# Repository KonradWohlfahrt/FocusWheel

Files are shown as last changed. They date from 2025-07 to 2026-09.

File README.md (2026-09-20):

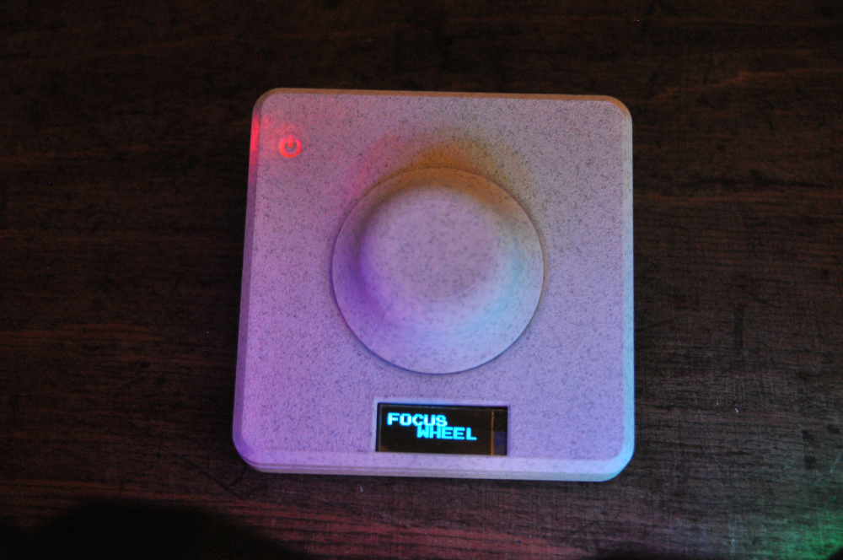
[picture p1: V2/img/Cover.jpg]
Cover


# Focus Wheel 2.0  
**Overview**  
Focus Wheel 2.0 is a compact, standalone focus and time-management device designed to help you stay productive during study sessions or focused work. It combines a clean, minimal design with touch controls, visual feedback, and flexible timer logic, all powered by a rechargeable battery. This second iteration is a major step up from the original Focus Wheel. It introduces battery operation with power-path management, touch-based controls, an integrated LED ring, and a more refined enclosure. The result is a polished desk companion that’s easy to use, highly customizable, and fun to build:  

[Instructables Guide](https://www.instructables.com/Focus-Wheel-20-Your-Next-Gen-Study-Assistant/)  

**Key Features**  
- *Four independent timers*  
Each timer can be configured individually with its own work and break durations. All settings are stored in EEPROM and persist across power cycles.
- *Built-in 20-20 rule*  
Optional eye-break reminders during work sessions help reduce eye strain. The reminder timing can be adjusted in software.
- *Touch-based controls*  
Capacitive touch buttons replace traditional mechanical switches, keeping the design clean and minimal.
- *Rotary encoder interface*  
A rotary encoder is used for intuitive navigation, timer selection, and value adjustments.
- *Integrated LED ring*  
WS2812B LEDs are placed directly on the PCB and provide visual feedback for timers, states, and effects.
- *OLED display*  
A small I2C OLED shows timer status, menus, battery information, and system feedback.
- *Sound and melodies*  
A passive buzzer allows the device to play different tones and melodies for notifications and timer events.
- *Battery powered with USB-C charging*  
The device runs on a LiPo battery and supports simultaneous charging and operation thanks to power-path management.
- *Battery monitoring & protection*  
Battery voltage, charge state, and power source (USB or battery) are monitored in software, with low-voltage shutdown for safety.  

***
# Materials:
| Component | Amount | Silkscreen label |
|:---|:---:|---:|
| 100n 0603 | 22 | C1,C4,C8,C12,C17,C19,C21-C36 |
| 100p 0805 | 1 | C15 |
| 100r 0805 | 2 | R9,R12 |
| 100u 1206 | 1 | C20 |
| 10k 0805 | 8 | R6,R11,R13,R18-R21,R28 |
| 10u 0805 | 5 | C3,C9,C11,C14,C16 |
| 15k 0805 | 1 | R15 |
| 1k 0805 | 4 | R7,R8,R10,R27 |
| 1k5 0805 | 1 | R4 |
| 1N4001 SMA | 1 | D3 |
| 1u 0805 | 3 | C2,C5,C18 |
| 2.2uH APH0420 | 1 | L1 |
| 309k 0805 | 1 | R17 |
| 330r 0805 | 1 | R24 |
| 33k 0805 | 1 | R25 |
| 39k 0805 | 1 | R3 |
| 3k9 0805 | 1 | R5 |
| 4.7u 0805 | 4 | C6,C7,C10,C13 |
| 4.7uH ANR3015 | 1 | L2 |
| 47k 0805 | 1 | R26 |
| 4k7 0805 | 2 | R22,R23 |
| 5k1 0805 | 2 | R1,R2 |
| 68k 0805 | 1 | R14 |
| 976k 0805 | 1 | R16 |
| AO3400A SOT-23 | 1 | Q3 |
| BQ24075RGT | 1 | U2 |
| Buzzer MLT-7525 | 1 | BZ1 |
| JST PH2.00mm 2P Horizontal | 1 | J2 |
| DW01A SOT-23-6 | 1 | U3 |
| ESP32-C3-WROOM-02 | 1 | U7 |
| FS8205A SOT-23-6 | 1 | Q1 |
| IRLML6402 SOT-23 | 1 | Q2 |
| LED 3.0mm | 2 | D1,D2 |
| MCP1640Cx-xCHY SOT-23-6 | 1 | U6 |
| MMBT2222A SOT-23 | 1 | Q4 |
| OLED I2C 0.91" | 1 | U10 |
| Rotary Encoder | 1 | SW1 |
| SN74LV1T34DBV SOT-23-5 | 1 | U11 |
| SS34 SMA | 1 | D20 |
| TLV62569DBV SOT-23-5 | 1 | U5 |
| TTP223 Touch Module | 3 | U4,U8,U9 |
| USB-C 16P | 1 | J1 |
| USBLC6-2SC6 SOT-23-6 | 1 | U1 |
| WS2812B 5050 | 16 | D4-D19 |
| Custom PCB | 1 | - |
| 3D printed housing | 1 | - |
| 303450 500mAh LiPo battery | 1 | - |
| M3 3x4.5mm threaded heat inserts | 6 | - |
| M3x4mm screw | 2 | - |
| M3x10mm screw | 4 | - |

***
# Schematic & PCB:
_Schematic of the Focus Wheel V2.1_
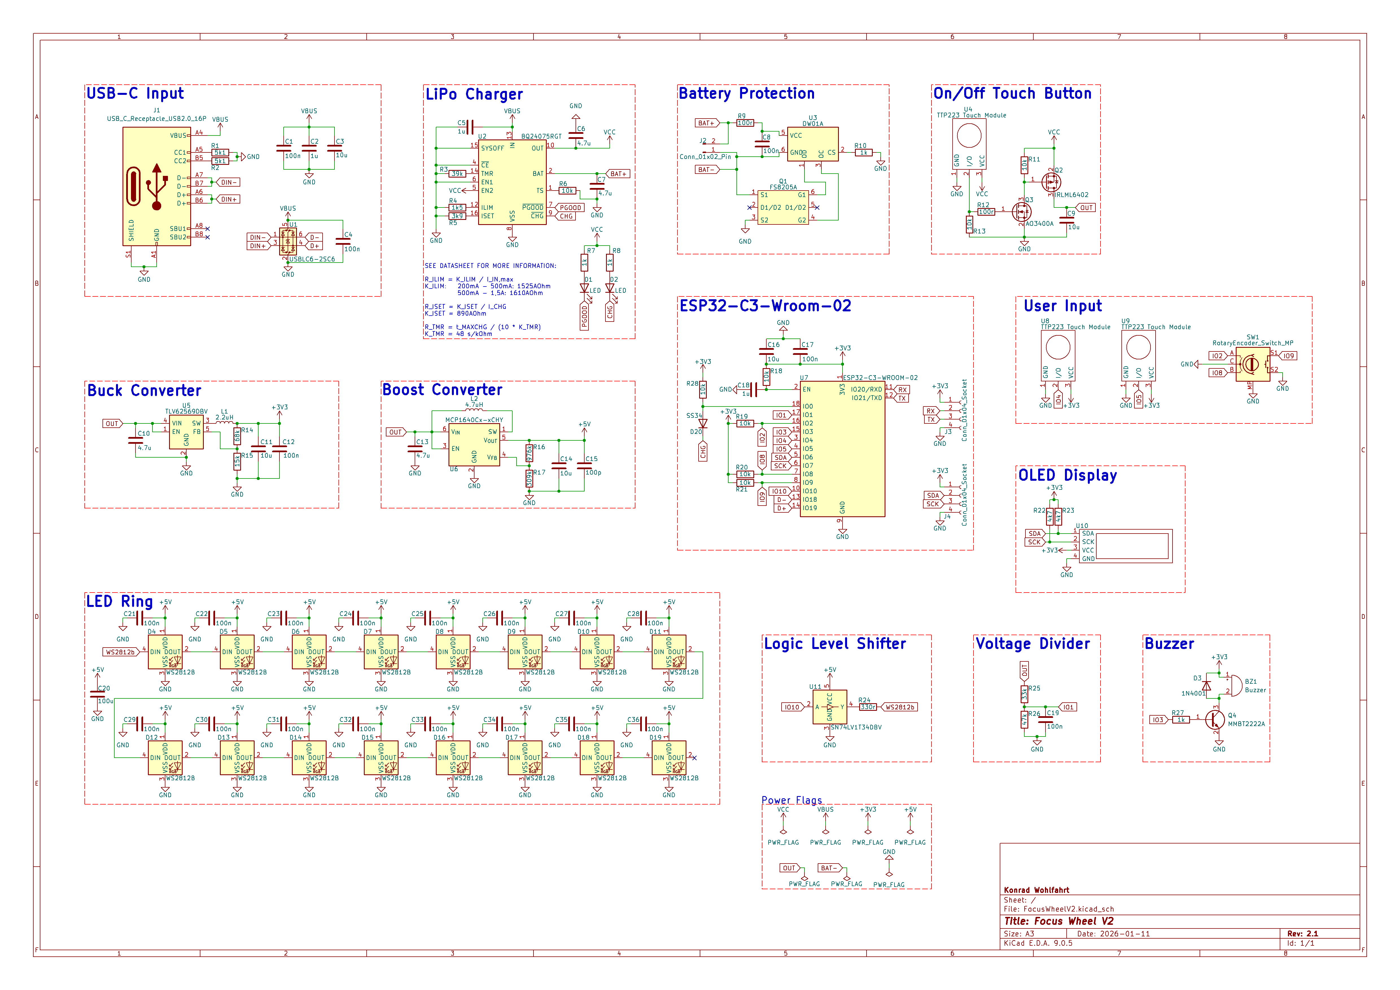
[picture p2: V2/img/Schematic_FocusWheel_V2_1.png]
Schematic

_Lables for soldering components_
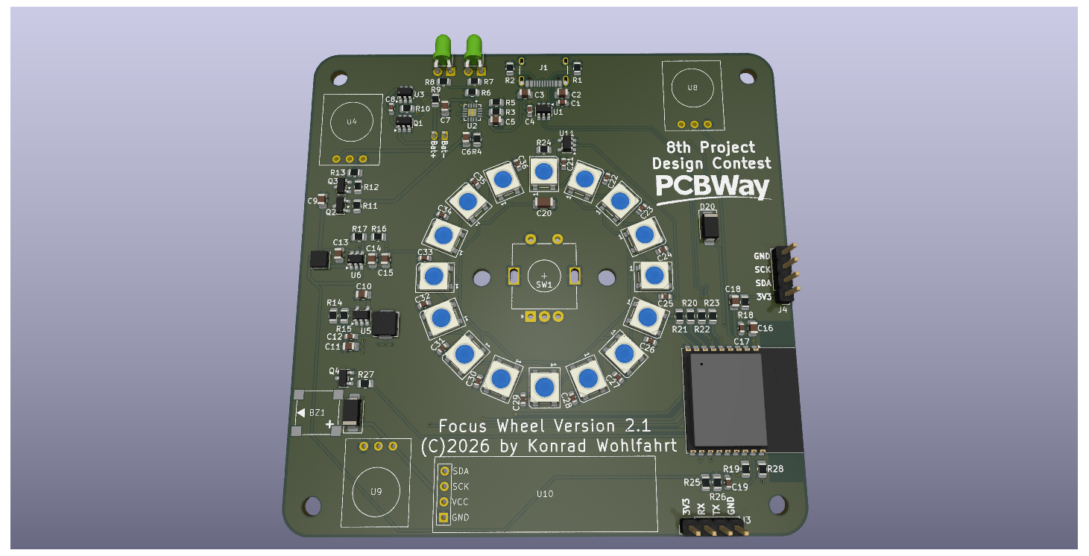
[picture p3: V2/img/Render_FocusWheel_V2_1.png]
PCB Render


***
# Programming
Programmed with the Arduino IDE and ESP32 board manager. Install the following libraries:
- [DonutStudioTimer](https://github.com/KonradWohlfahrt/Arduino-Timer-Library)
- [RotaryEncoder](https://github.com/mathertel/RotaryEncoder)
- [FastLED](https://github.com/FastLED/FastLED)
- [U8g2](https://github.com/olikraus/u8g2)

**Uploading:**  
Board: `ESP32C3 Dev Module`\
Settings:
```cpp
USB CDC On Boot: "Enabled" <- to make USB Serial work  
CPU Frequency: "160MHz (WiFi)"  
Core Debug Level: "None"  
Erase All Flash Before Sketch Upload: "Disabled"  
Flash Frequency: "80MHz"  
Flash Mode: "QIO"  
Flash Size: "4MB (32Mb)"  
JTAG Adapter: "Disabled"  
Partition Scheme: "Default 4MB with spiffs (1.2MB APP/1.5MB SPIFFS)"  
Upload Speed: "921600"  
Zigbee Mode: "Disabled"  
Programmer: "Esptool"  
```
Connection via USB-C.\
Press the knob button (Flash) when powering up the device for the first time.

***
# 3D Printing
Print `FocusWheel_Bottom` and `FocusWheel_Top` - depending on what components you would like to use. Finally, print `Knob`. Put in the six threaded heat inserts and screw everything together. The knob slides on top.
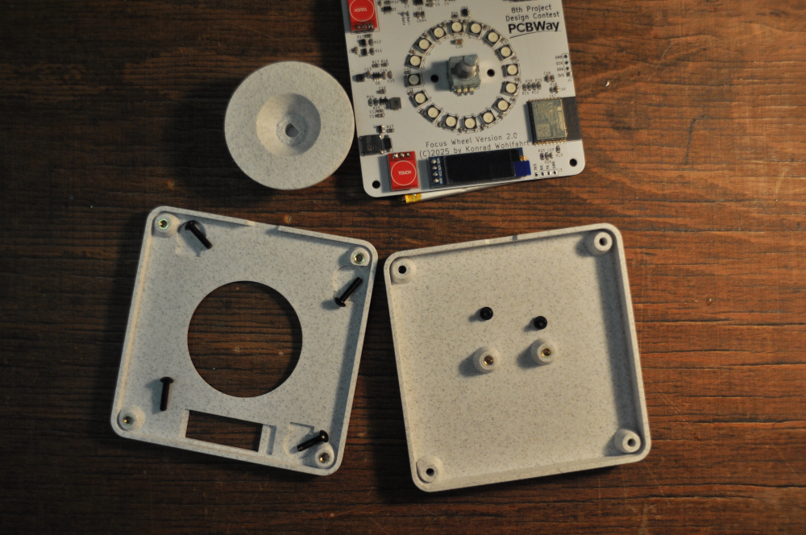
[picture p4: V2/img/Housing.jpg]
Housing


***
# Functions
The following button functions are used:
- bottom button: enable/disable sound
- middle button: start timer, pause timer, change selection (rotation)
- top button: skip timers, enter/exit settings

**Customization & Hacking**  
All firmware is written for the Arduino ecosystem, and the code is intended to be easy to extend and experiment with. This project is fully open to customization. You can:
- Modify timer logic and behaviors
- Change LED effects and animations
- Add or replace melodies
- Adjust UI flow and menu structure

**Final Notes**  
Focus Wheel 2.0 is meant to be both a useful productivity tool and an enjoyable electronics project. Whether you build it as-is or use it as a base for your own ideas, feel free to experiment, improve, and make it your own. If you build one, I’d love to see it—share your version and ideas!  

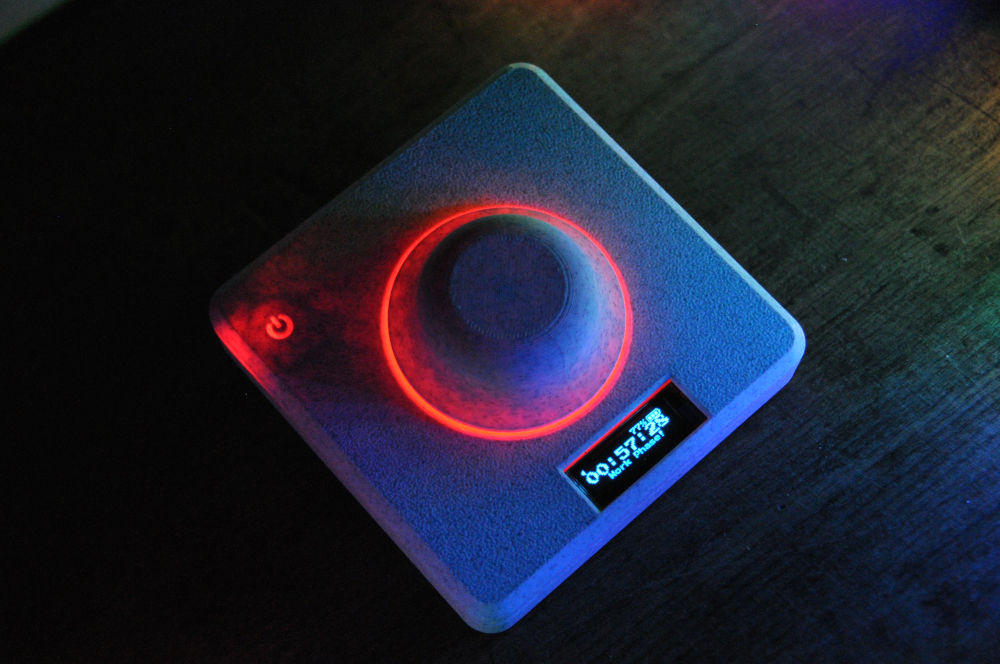
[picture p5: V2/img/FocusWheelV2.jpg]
Focus Wheel V2


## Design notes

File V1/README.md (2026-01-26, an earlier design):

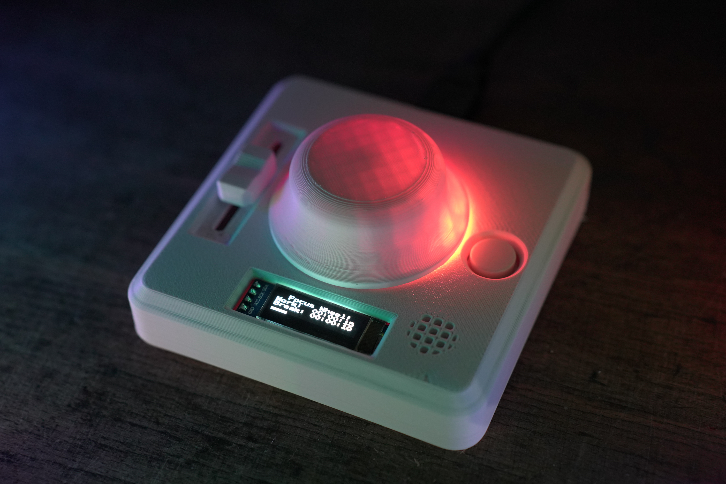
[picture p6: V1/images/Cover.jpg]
Cover


# Focus Wheel
The Focus Wheel is a customizable desk companion designed to help you stay focused, manage study sessions, and take effective breaks. Powered by an ESP32-C3, it features a rotary encoder, buzzer, LED ring, OLED display, and optional slider — all neatly packed into a 3D-printed enclosure.
This project combines hardware and software to provide:
- Multiple focus and break timers
- Visual and audible notifications
- Customizable controls via knob, button, and slider
- Expandability for future features (e.g., media control or BLE functionality)\

Whether you're a student, maker, or just looking to build a functional productivity gadget, the Focus Wheel is a great weekend project — with lots of room for upgrades! Check out the in-depth [guide](https://www.instructables.com/Focus-Wheel-Your-Desk-Study-Buddy/) at instructables!\

**Sponsored by PCBWay!**
This project was made possible with the help of [PCBWay](https://www.pcbway.com/) — a reliable PCB manufacturing service offering high-quality boards at great prices. If you’re looking to bring your electronics project to life with professionally fabricated PCBs, check them out!
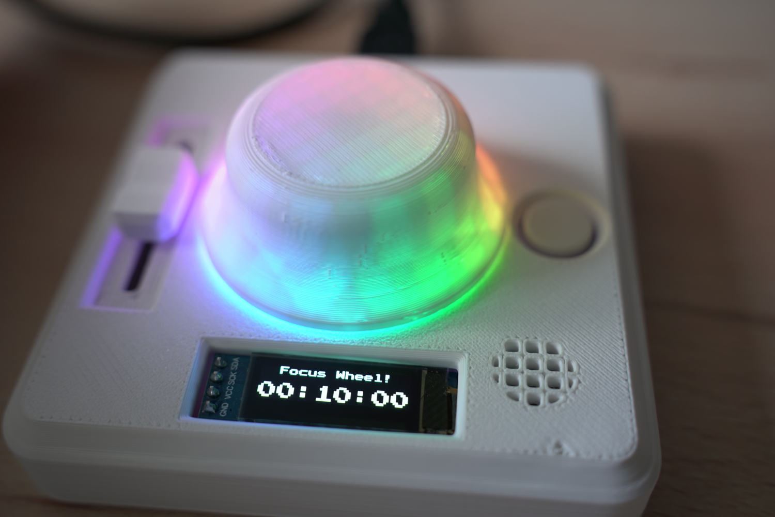
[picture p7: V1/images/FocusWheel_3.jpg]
Focus Wheel


***
# Materials:
| Component | Amount | Silkscreen label |
|:---|:---:|---:|
| custom pcb | 1 | - |
| MMBT2222A | 1 | Q1 |
| 10uF 0805 | 3 | C1,C3,C9 |
| 100nF 0805 | 4 | C2,C4,C8,C11 |
| 1uF 0805 | 2 | C5,C10 |
| 47pF 0805 | 2 | C6,C7 |
| 100uF 1206 | 1 | C12 |
| 10k 0805 | 5 | R1,R2,R5,R6,R11 |
| 0r 0805 | 3 | R3,R4,R7 |
| 330r 0805 | 1 | R8 |
| 33r 0805 | 1 | R9 |
| 1k 0805 | 1 | R10 |
| 220k 0805 | 1 | R12 |
| 100k 0805 | 1 | R13 |
| 45mm fader | 1 | RS1 |
| Rotary encoder | 1 | SW1 |
| Tactile switch 12x12mm | 1 | SW2 |
| SMD switch 3x6x5mm | 1 | KEY1 |
| Buzzer 12x9mm | 1 | BUZZER1 |
| USB3.0 A socket | 1 | USB1 |
| ESP32-C3-WROOM-02 | 1 | U1 |
| AMS1117-3.3V | 1 | U2 |
| 0.91" OLED | 1 | U3 |
| threaded heat insert m3 x 4.5mm | 6 | - |
| M3x14mm screw | 4 | - |
| M3x4mm screw | 2 | - |
| USB-A cable (male to male) | 1 | - |

***
# Schematic:
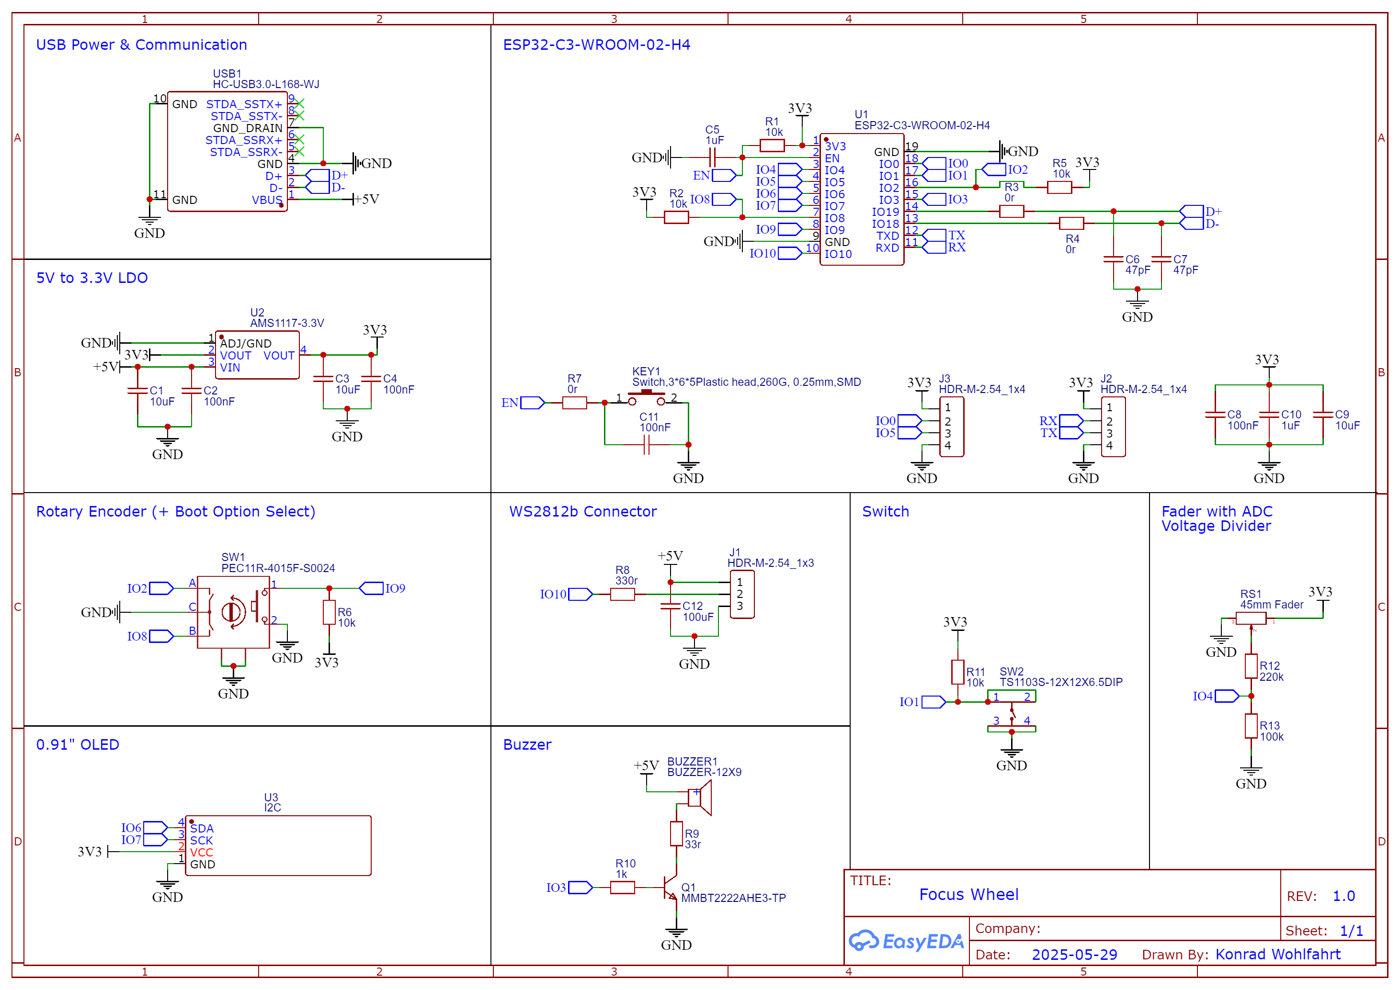
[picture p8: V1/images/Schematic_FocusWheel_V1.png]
Schematic

_Schematic of the Focus Wheel_
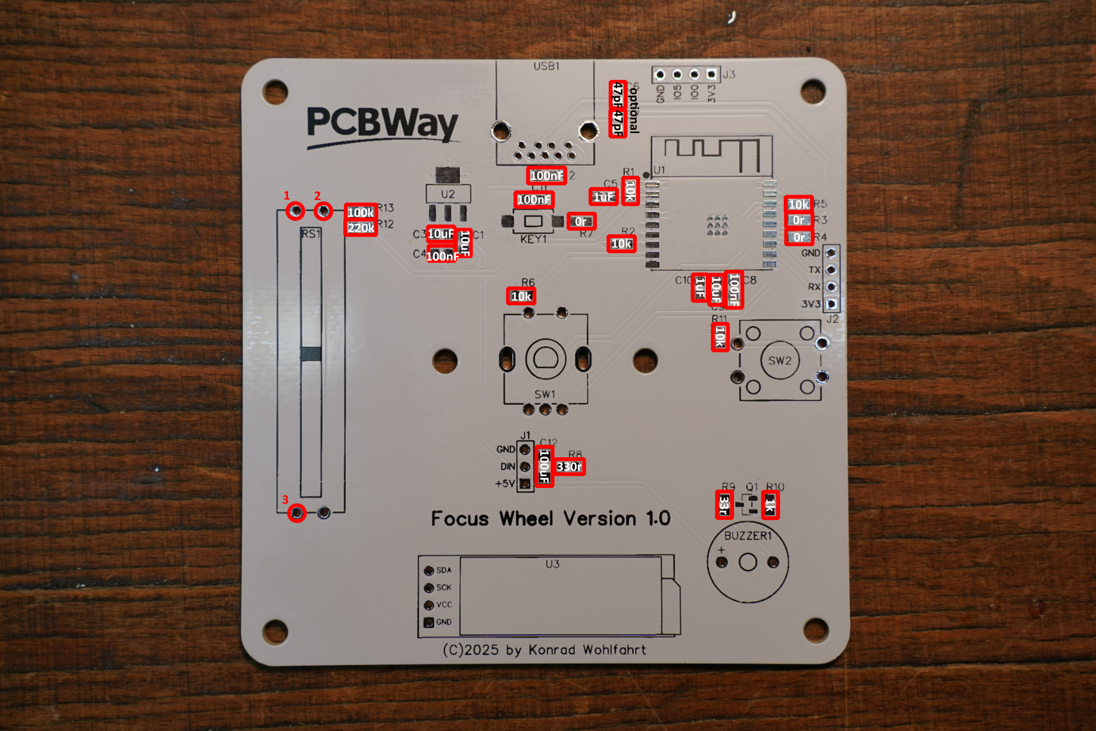
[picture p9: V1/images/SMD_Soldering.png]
Soldering Lables

_Lables for soldering components_

***
# Programming
Programmed with the Arduino IDE and ESP32 board manager. 
Install the following libraries:
- [DonutStudioTimer](https://github.com/KonradWohlfahrt/Arduino-Timer-Library)
- [RotaryEncoder](https://github.com/mathertel/RotaryEncoder)
- [FastLED](https://github.com/FastLED/FastLED)
- [U8g2](https://github.com/olikraus/u8g2)

**Uploading:**
Board: `ESP32C3 Dev Module`\
Settings: default\
Connection via USB cable.\
Press the knob button (Flash) when powering up the device, it also seems uploading works without doing so.

***
# 3D Printing
Print `Housing Bottom` and one of the `Housing Top` options - depending on what components you would like to use. Finally, print both `Fading Knob` and `Knob`. Put in the six threaded heat inserts and screw everything together. The knobs slide on top.
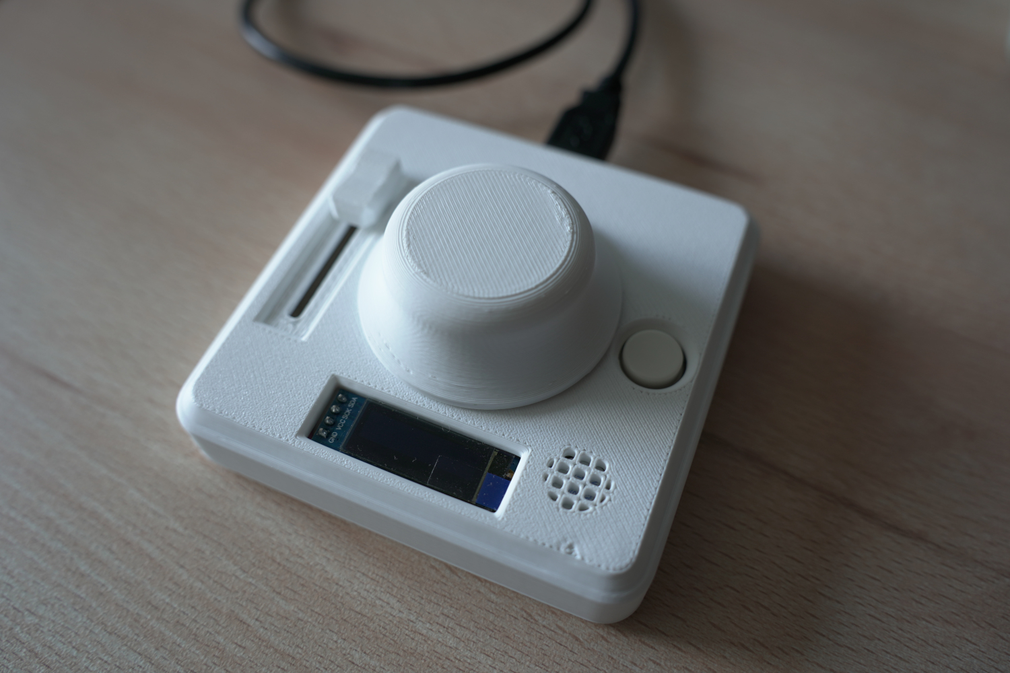
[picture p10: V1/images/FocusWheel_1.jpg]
Focus Wheel


***
# Functions
The following button functions are used in the examples:
- middle button: start timer, pause timer, change selection
- rotating middle button: change timer values or timers
- right button: edit timers, skip timers
- long press right button (only `Timer.ino`): save timer to eeprom

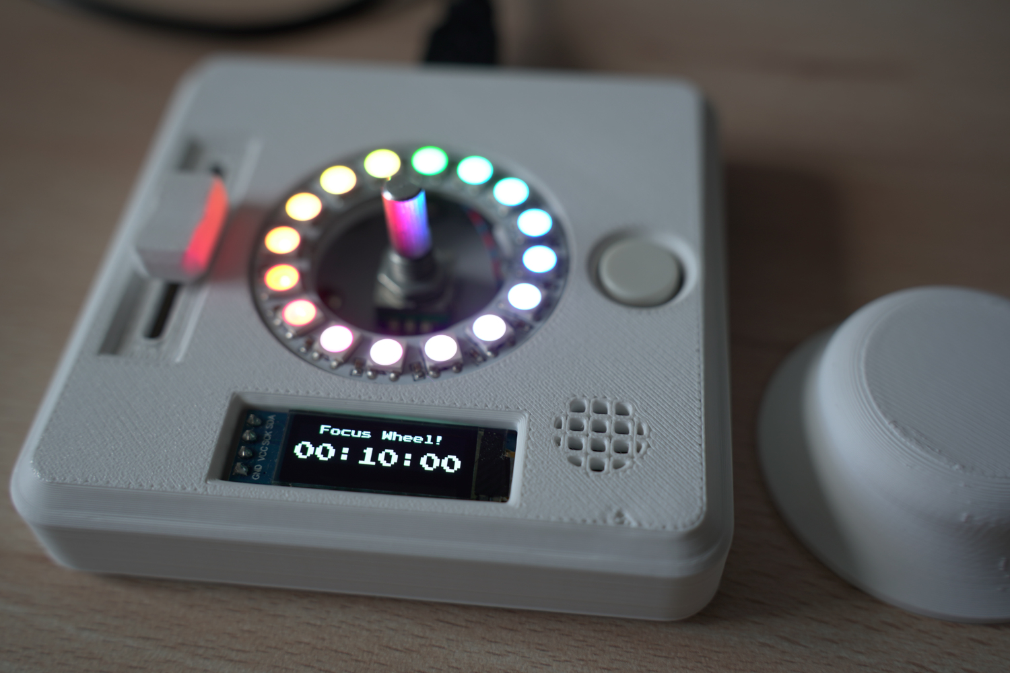
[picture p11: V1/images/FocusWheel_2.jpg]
Focus Wheel


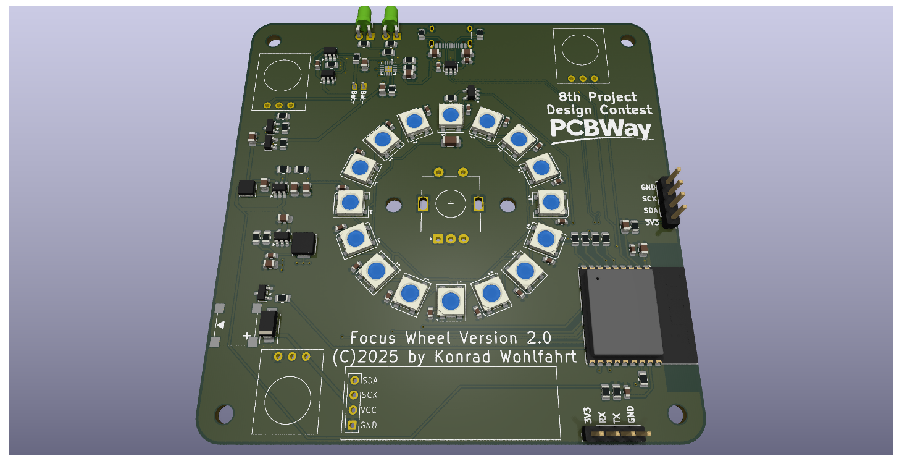
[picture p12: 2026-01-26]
V2/img/Render_FocusWheel_V2.png

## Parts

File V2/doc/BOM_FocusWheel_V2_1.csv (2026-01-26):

Reference | Qty | Value | DNP | Exclude from BOM | Exclude from Board | Footprint | Datasheet
BZ1 | 1 | Buzzer |  |  |  | KonradsLibrary:Huaneng MLT-7525 | ~
C1,C4,C8,C12,C17,C19,C21,C22,C23,C24,C25,C26,C27,C28,C29,C30,C31,C32,C33,C34,C35,C36 | 22 | 100n |  |  |  | Capacitor_SMD:C_0603_1608Metric | ~
C2,C5,C18 | 3 | 1u |  |  |  | Capacitor_SMD:C_0805_2012Metric | ~
C3,C9,C11,C14,C16 | 5 | 10u |  |  |  | Capacitor_SMD:C_0805_2012Metric | ~
C6,C7,C10,C13 | 4 | 4.7u |  |  |  | Capacitor_SMD:C_0805_2012Metric | ~
C15 | 1 | 100p |  |  |  | Capacitor_SMD:C_0805_2012Metric | ~
C20 | 1 | 100u |  |  |  | Capacitor_SMD:C_1206_3216Metric | ~
D1,D2 | 2 | LED |  |  |  | LED_THT:LED_D3.0mm_Horizontal_O1.27mm_Z2.0mm | ~
D3 | 1 | 1N4001 |  |  |  | Diode_SMD:D_SMA | ~
D4,D5,D6,D7,D8,D9,D10,D11,D12,D13,D14,D15,D16,D17,D18,D19 | 16 | WS2812B |  |  |  | LED_SMD:LED_WS2812B_PLCC4_5.0x5.0mm_P3.2mm | https://cdn-shop.adafruit.com/datasheets/WS2812B.pdf
D20 | 1 | SS34 |  |  |  | Diode_SMD:D_SMA | ~
J1 | 1 | USB_C_Receptacle_USB2.0_16P |  |  |  | Connector_USB:USB_C_Receptacle_HCTL_HC-TYPE-C-16P-01A | https://www.usb.org/sites/default/files/documents/usb_type-c.zip
J2 | 1 | Conn_01x02_Pin |  |  |  | Connector_JST:JST_PH_S2B-PH-K_1x02_P2.00mm_Horizontal | ~
J3,J4 | 2 | Conn_01x04_Socket |  |  |  | Connector_PinHeader_2.54mm:PinHeader_1x04_P2.54mm_Vertical | ~
L1 | 1 | 2.2uH |  |  |  | Inductor_SMD:L_APV_APH0420 | ~
L2 | 1 | 4.7uH |  |  |  | Inductor_SMD:L_APV_ANR3015 | ~
Q1 | 1 | FS8205A |  |  |  | Package_TO_SOT_SMD:SOT-23-6
Q2 | 1 | IRLML6402 |  |  |  | Package_TO_SOT_SMD:SOT-23 | https://www.infineon.com/dgdl/irlml6402pbf.pdf?fileId=5546d462533600a401535668d5c2263c
Q3 | 1 | AO3400A |  |  |  | Package_TO_SOT_SMD:SOT-23 | http://www.aosmd.com/pdfs/datasheet/AO3400A.pdf
Q4 | 1 | MMBT2222A |  |  |  | Package_TO_SOT_SMD:SOT-23 | https://assets.nexperia.com/documents/data-sheet/MMBT2222A.pdf
R1,R2 | 2 | 5k1 |  |  |  | Resistor_SMD:R_0805_2012Metric | ~
R3 | 1 | 39k |  |  |  | Resistor_SMD:R_0805_2012Metric | ~
R4 | 1 | 1k5 |  |  |  | Resistor_SMD:R_0805_2012Metric | ~
R5 | 1 | 3k9 |  |  |  | Resistor_SMD:R_0805_2012Metric | ~
R6,R11,R13,R18,R19,R20,R21,R28 | 8 | 10k |  |  |  | Resistor_SMD:R_0805_2012Metric | ~
R7,R8,R10,R27 | 4 | 1k |  |  |  | Resistor_SMD:R_0805_2012Metric | ~
R9,R12 | 2 | 100r |  |  |  | Resistor_SMD:R_0805_2012Metric | ~
R14 | 1 | 68k |  |  |  | Resistor_SMD:R_0805_2012Metric | ~
R15 | 1 | 15k |  |  |  | Resistor_SMD:R_0805_2012Metric | ~
R16 | 1 | 976k |  |  |  | Resistor_SMD:R_0805_2012Metric | ~
R17 | 1 | 309k |  |  |  | Resistor_SMD:R_0805_2012Metric | ~
R22,R23 | 2 | 4k7 |  |  |  | Resistor_SMD:R_0805_2012Metric | ~
R24 | 1 | 330r |  |  |  | Resistor_SMD:R_0805_2012Metric | ~
R25 | 1 | 33k |  |  |  | Resistor_SMD:R_0805_2012Metric | ~
R26 | 1 | 47k |  |  |  | Resistor_SMD:R_0805_2012Metric | ~
SW1 | 1 | RotaryEncoder_Switch_MP |  |  |  | Rotary_Encoder:RotaryEncoder_Alps_EC11E-Switch_Vertical_H20mm | ~
U1 | 1 | USBLC6-2SC6 |  |  |  | Package_TO_SOT_SMD:SOT-23-6 | https://www.st.com/resource/en/datasheet/usblc6-2.pdf
U2 | 1 | BQ24075RGT |  |  |  | Package_DFN_QFN:VQFN-16-1EP_3x3mm_P0.5mm_EP1.6x1.6mm | http://www.ti.com/lit/ds/symlink/bq24075.pdf
U3 | 1 | DW01A |  |  |  | Package_TO_SOT_SMD:SOT-23-6 | https://hmsemi.com/downfile/DW01A.PDF
U4,U8,U9 | 3 | TTP223 Touch Module |  |  |  | KonradsLibrary:TTP223 Touch Module
U5 | 1 | TLV62569DBV |  |  |  | Package_TO_SOT_SMD:SOT-23-5 | http://www.ti.com/lit/ds/symlink/tlv62569.pdf
U6 | 1 | MCP1640Cx-xCHY |  |  |  | Package_TO_SOT_SMD:SOT-23-6 | http://ww1.microchip.com/downloads/en/DeviceDoc/20002234D.pdf
U7 | 1 | ESP32-C3-WROOM-02 |  |  |  | RF_Module:ESP32-C3-WROOM-02 | https://www.espressif.com/sites/default/files/documentation/esp32-c3-wroom-02_datasheet_en.pdf
U10 | 1 | OLED I2C 0.91" |  |  |  | KonradsLibrary:OLED I2C 0.91
U11 | 1 | SN74LV1T34DBV |  |  |  | Package_TO_SOT_SMD:SOT-23-5 | https://www.ti.com/lit/ds/symlink/sn74lv1t34.pdf

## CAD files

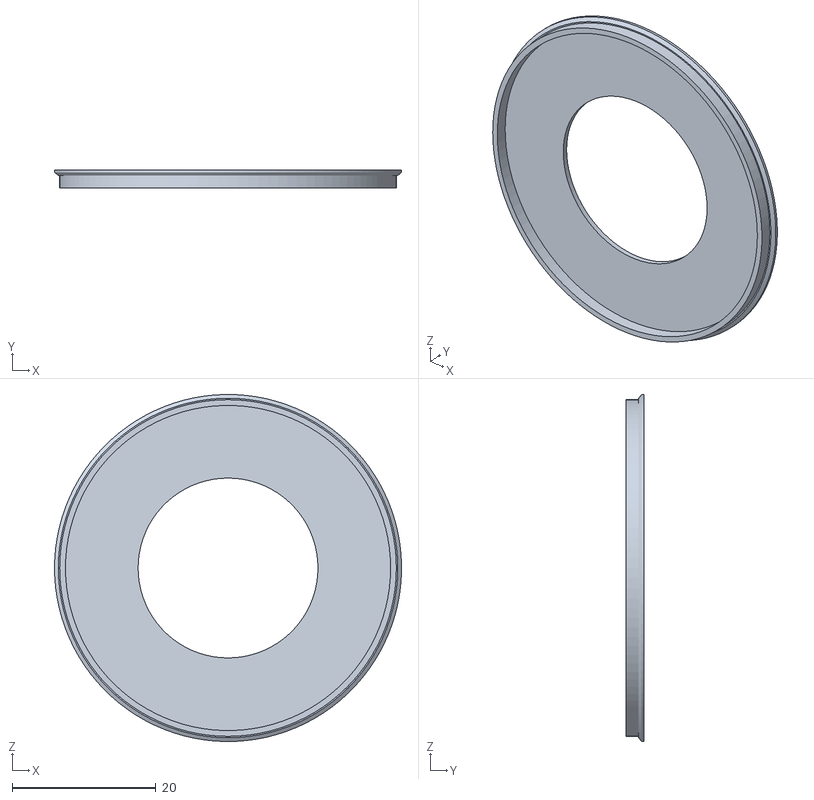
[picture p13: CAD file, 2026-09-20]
V2/cad/FocusWheel_Diffuser.stl
48.2 x 2.50 x 48.2

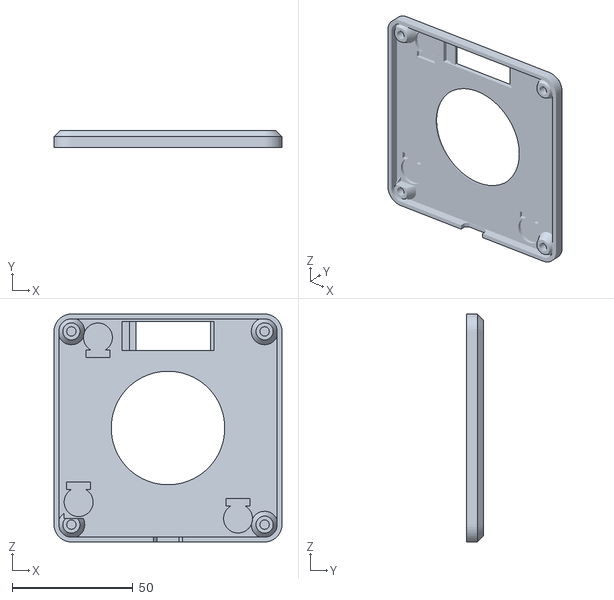
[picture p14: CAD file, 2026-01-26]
V2/cad/FocusWheel_Top.stl
94.4 x 7.00 x 94.4

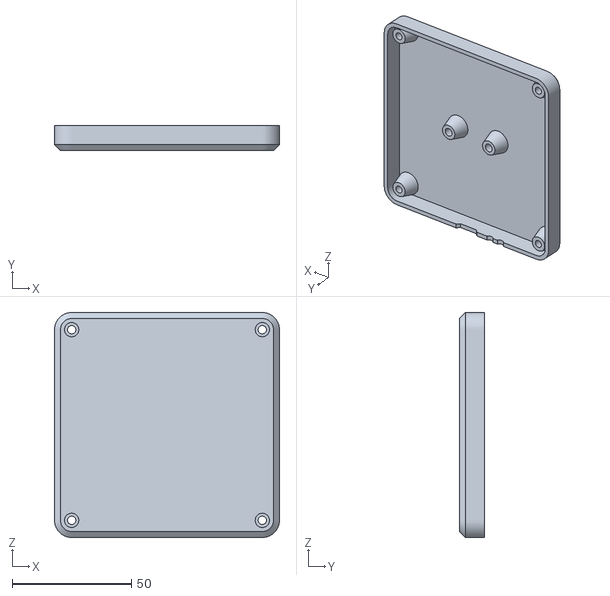
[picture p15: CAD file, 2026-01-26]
V2/cad/FocusWheel_Bottom_LED.stl
94.4 x 10.6 x 94.4

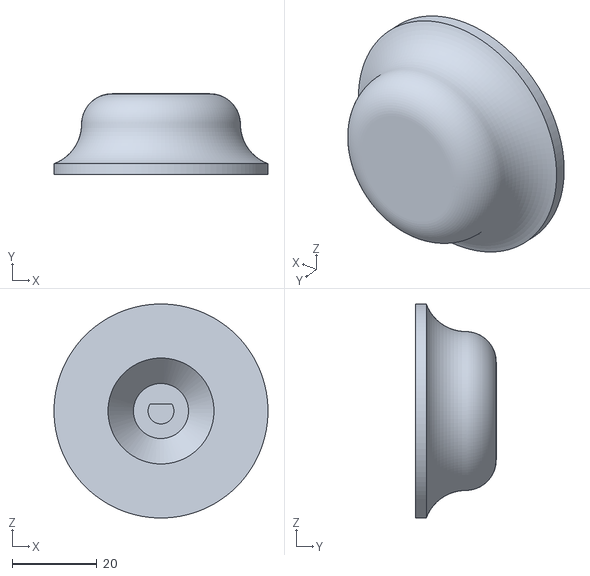
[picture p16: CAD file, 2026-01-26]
V2/cad/FocusWheel_Knob.stl
50.5 x 19.0 x 50.5

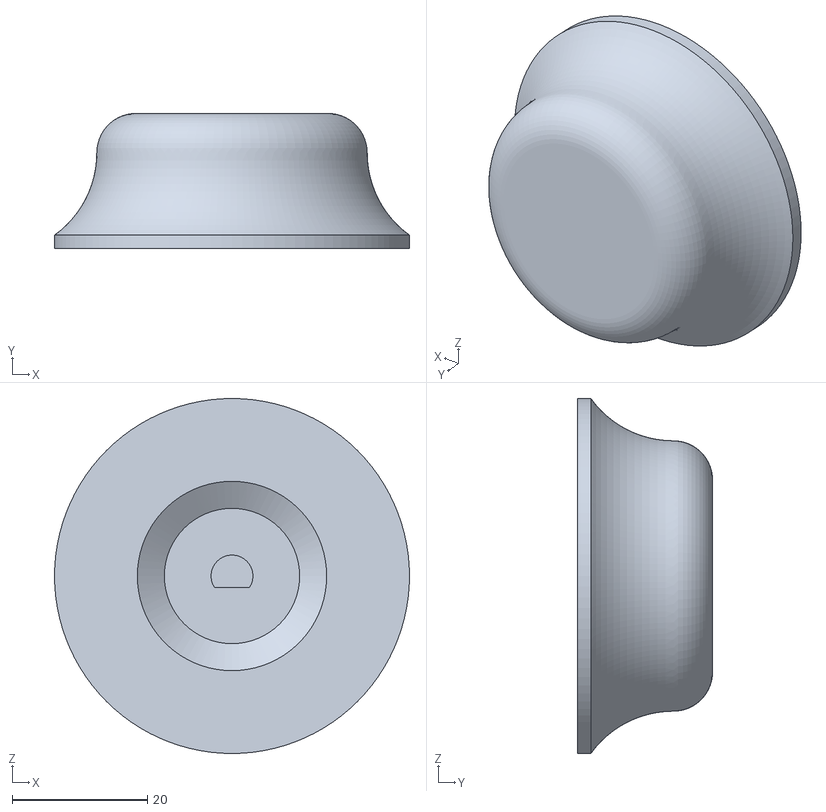
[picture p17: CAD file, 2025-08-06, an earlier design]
V1/cad/Knob.stl
52.5 x 20.0 x 52.5

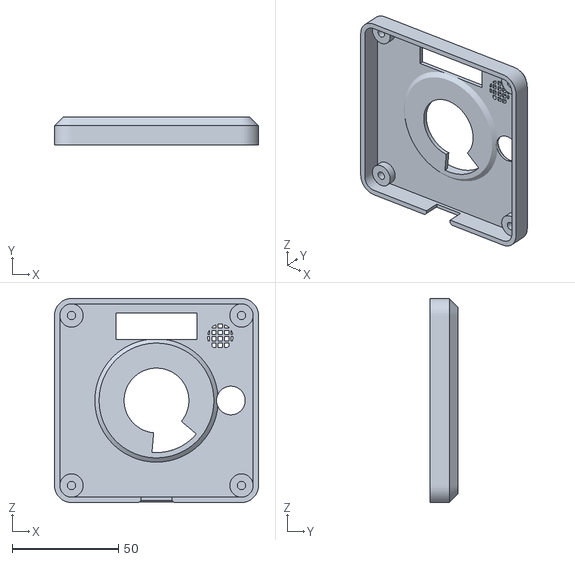
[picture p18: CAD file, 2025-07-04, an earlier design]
V1/cad/Housing Top OLED.stl
96.0 x 13.0 x 96.0

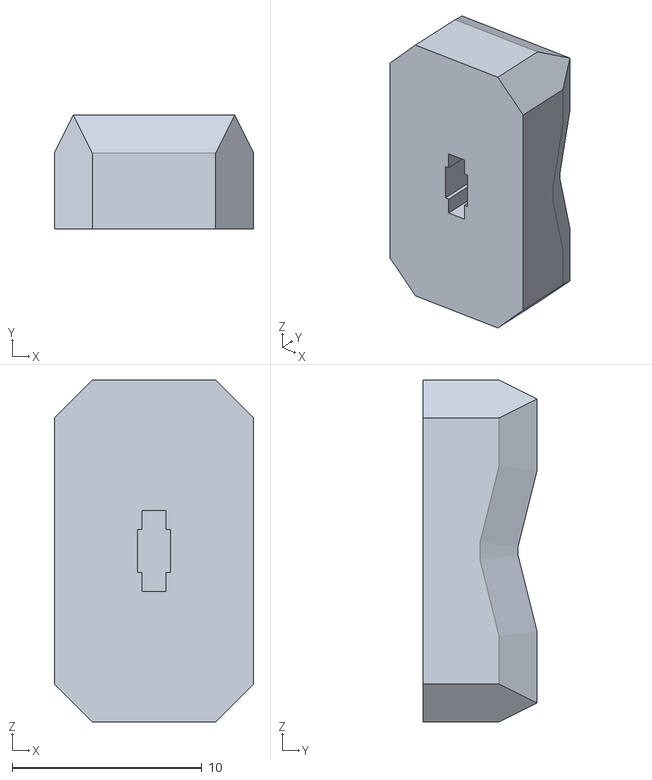
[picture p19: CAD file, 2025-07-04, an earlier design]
V1/cad/Fading Knob.stl
10.5 x 6.00 x 18.0

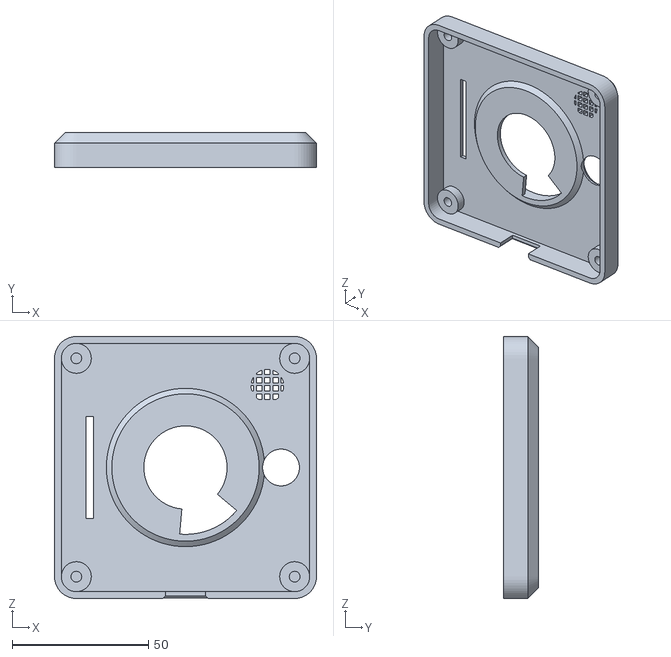
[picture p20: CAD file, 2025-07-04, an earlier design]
V1/cad/Housing Top Slider.stl
96.0 x 13.0 x 96.0

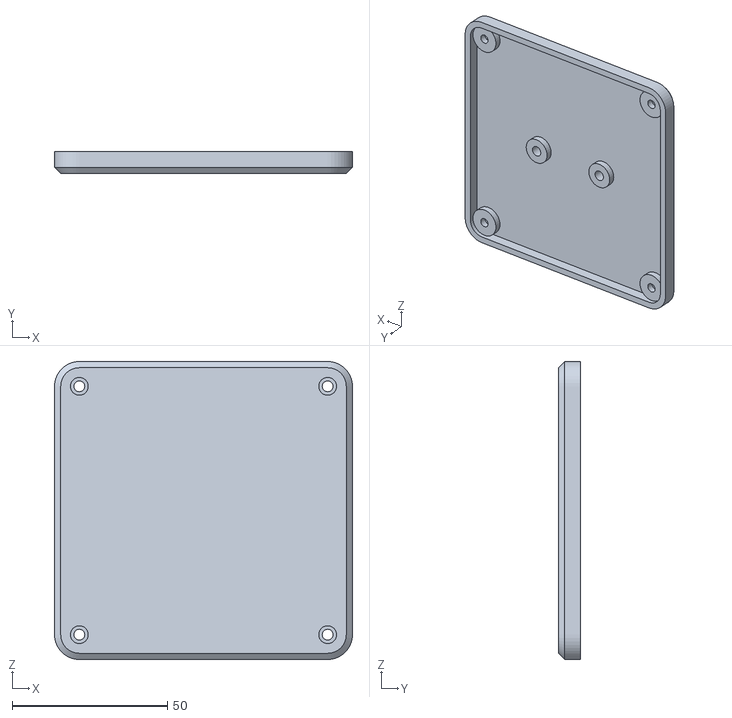
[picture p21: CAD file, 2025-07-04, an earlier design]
V1/cad/Housing Bottom.stl
96.0 x 7.10 x 96.0

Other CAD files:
V2/cad/FocusWheel_Top_LED.stl
V2/cad/FocusWheel_Bottom.stl
V1/cad/Housing Top OLED Slider.stl
V1/cad/Housing Top.stl

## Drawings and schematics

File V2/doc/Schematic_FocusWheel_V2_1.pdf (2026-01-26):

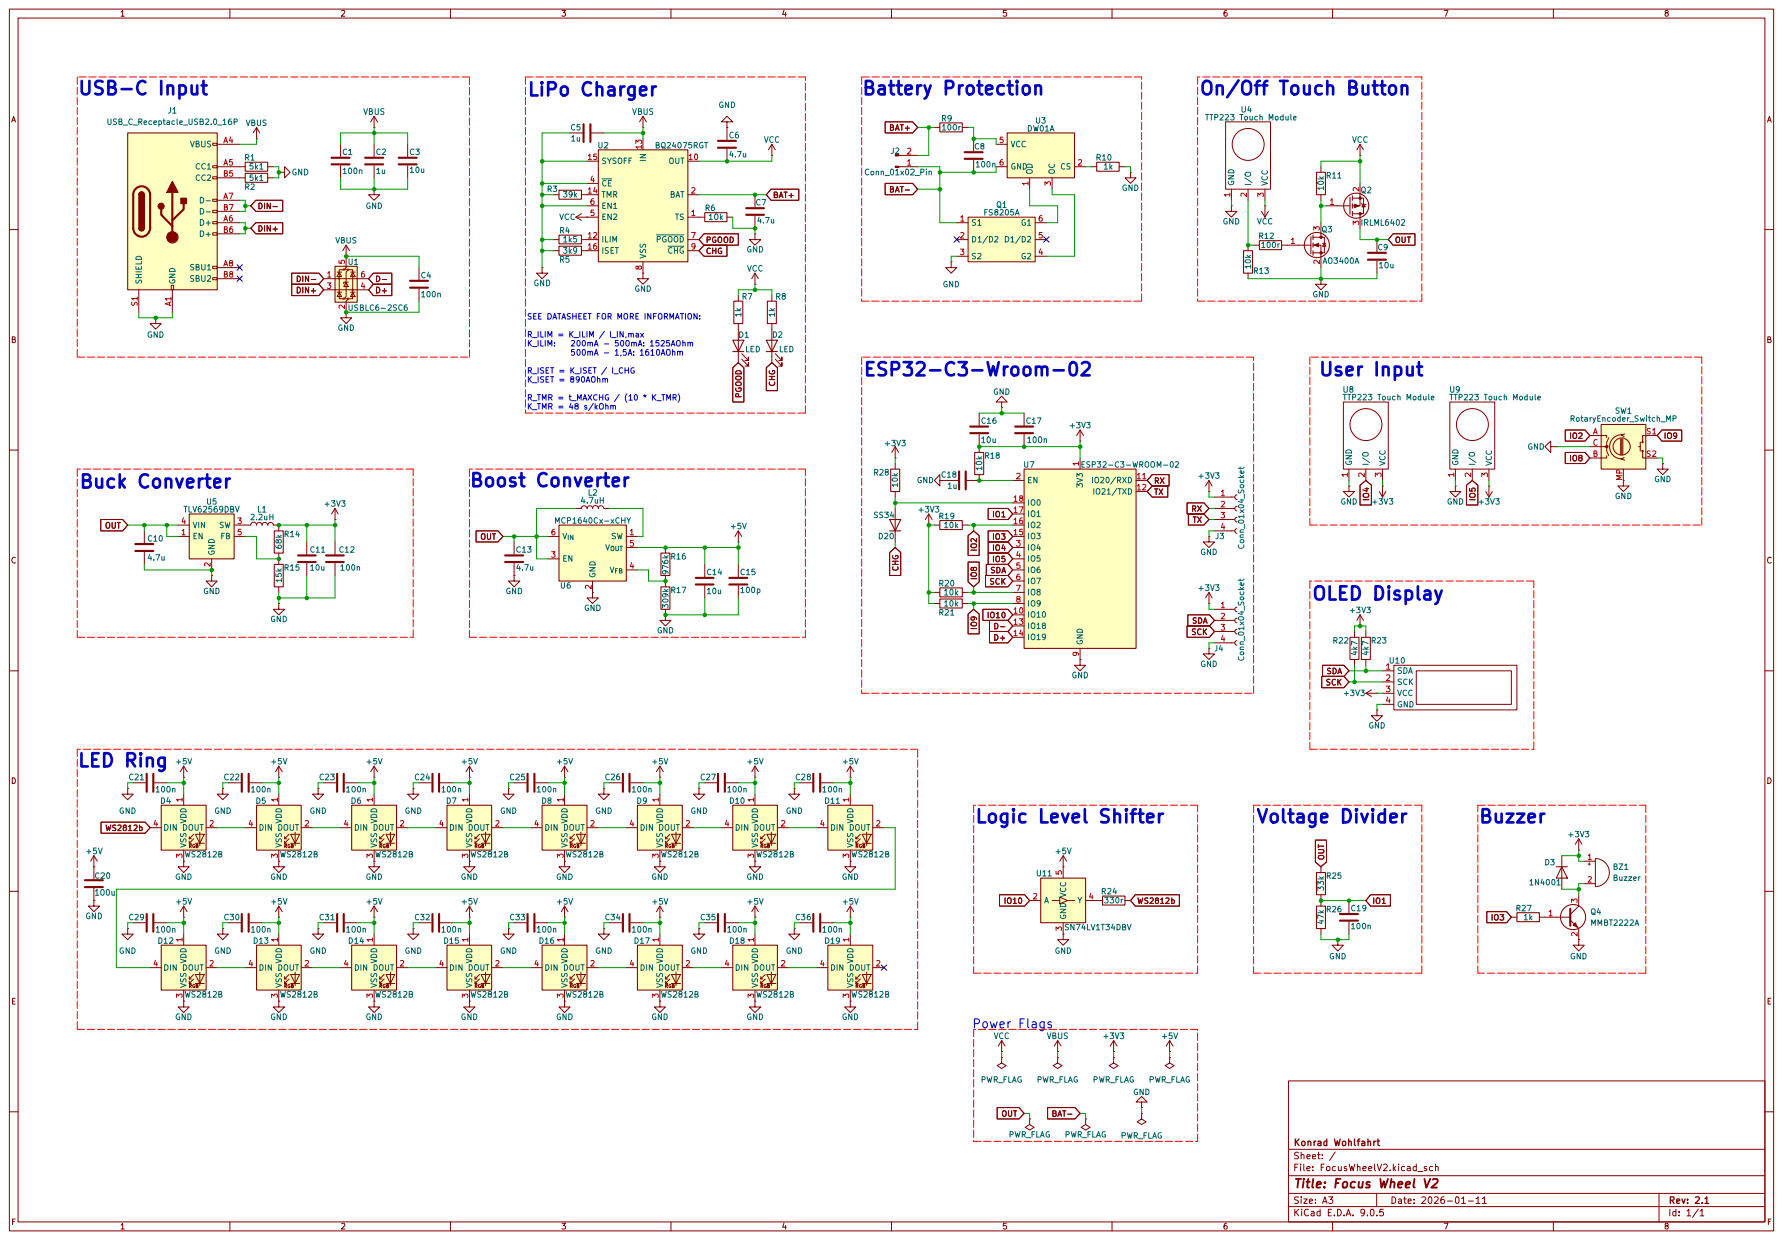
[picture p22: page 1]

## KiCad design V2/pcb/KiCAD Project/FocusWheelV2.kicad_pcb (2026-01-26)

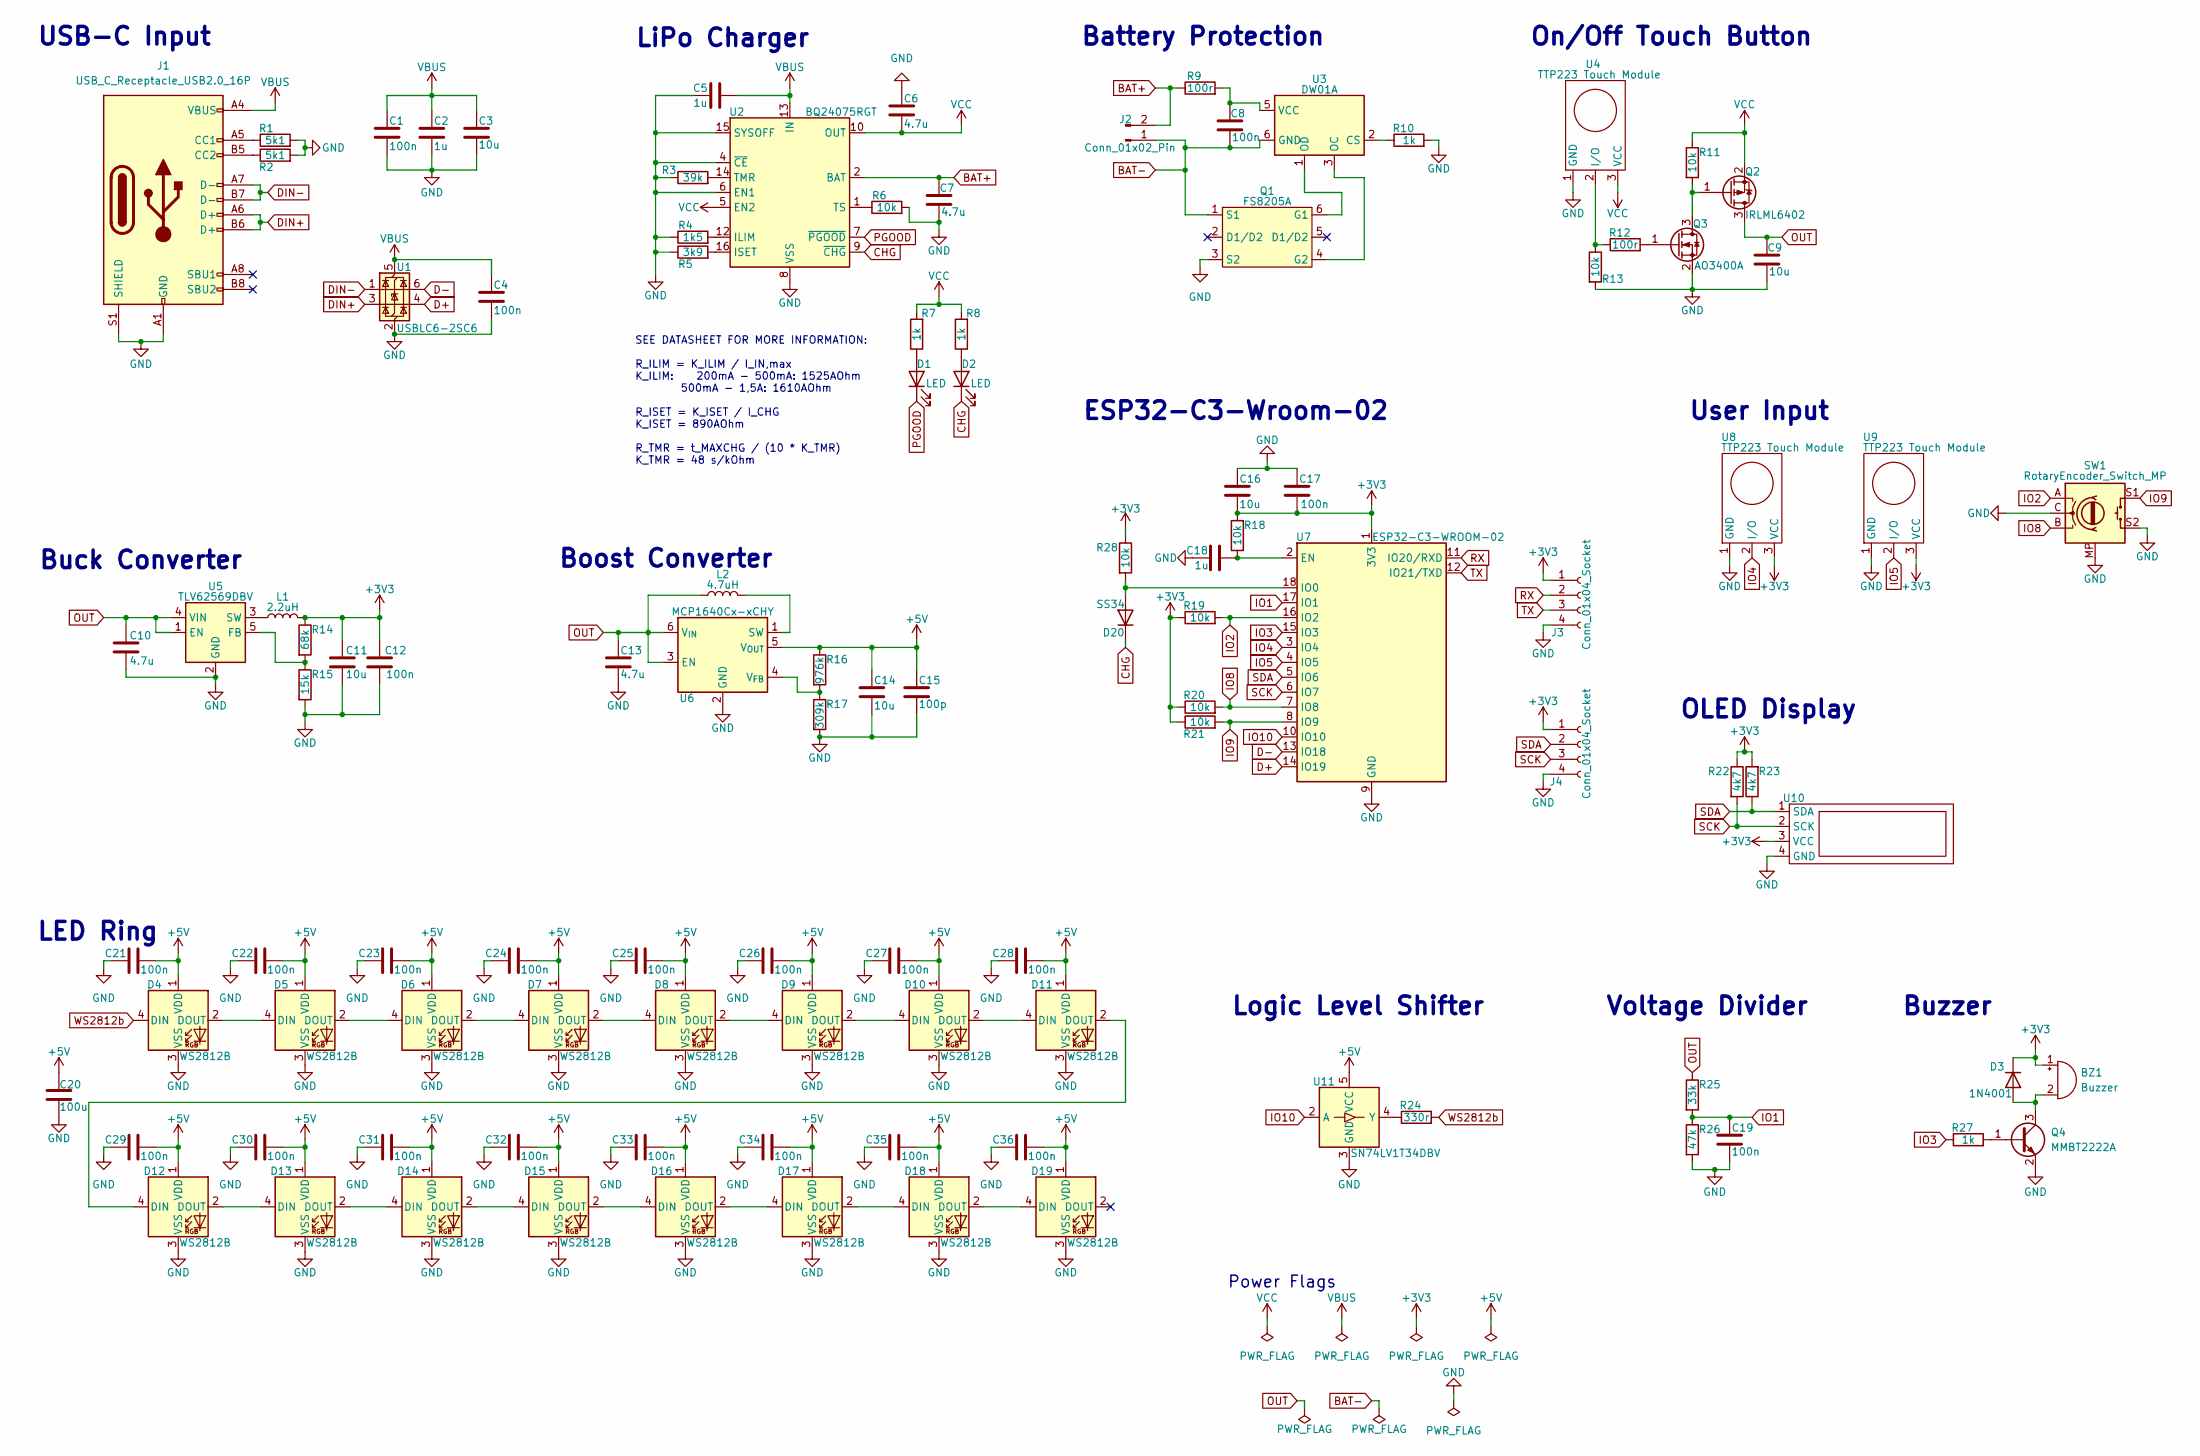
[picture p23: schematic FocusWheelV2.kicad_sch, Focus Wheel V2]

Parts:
BZ1: Buzzer; Huaneng MLT-7525
C1, C4, C8, C12, C17, C19, C21, C22, C23, C24, C25, C26, C27, C28, C29, C30, C31, C32, C33, C34, C35, C36: 100n; C_0603_1608Metric
C2, C5, C18: 1u; C_0805_2012Metric
C3, C9, C11, C14, C16: 10u; C_0805_2012Metric
C6, C7, C10, C13: 4.7u; C_0805_2012Metric
C15: 100p; C_0805_2012Metric
C20: 100u; C_1206_3216Metric
D1, D2: LED; LED_D3.0mm_Horizontal_O1.27mm_Z2.0mm
D3: 1N4001; D_SMA
D4, D5, D6, D7, D8, D9, D10, D11, D12, D13, D14, D15, D16, D17, D18, D19: WS2812B; LED_WS2812B_PLCC4_5.0x5.0mm_P3.2mm
D20: SS34; D_SMA
J1: USB_C_Receptacle_USB2.0_16P; USB_C_Receptacle_HCTL_HC-TYPE-C-16P-01A
J2: Conn_01x02_Pin; JST_PH_S2B-PH-K_1x02_P2.00mm_Horizontal
J3, J4: Conn_01x04_Socket; PinHeader_1x04_P2.54mm_Vertical
L1: 2.2uH; L_APV_APH0420
L2: 4.7uH; L_APV_ANR3015
Q1: FS8205A; SOT-23-6
Q2: IRLML6402; SOT-23
Q3: AO3400A; SOT-23
Q4: MMBT2222A; SOT-23
R1, R2: 5k1; R_0805_2012Metric
R3: 39k; R_0805_2012Metric
R4: 1k5; R_0805_2012Metric
R5: 3k9; R_0805_2012Metric
R6, R11, R13, R18, R19, R20, R21, R28: 10k; R_0805_2012Metric
R7, R8, R10, R27: 1k; R_0805_2012Metric
R9, R12: 100r; R_0805_2012Metric
R14: 68k; R_0805_2012Metric
R15: 15k; R_0805_2012Metric
R16: 976k; R_0805_2012Metric
R17: 309k; R_0805_2012Metric
R22, R23: 4k7; R_0805_2012Metric
R24: 330r; R_0805_2012Metric
R25: 33k; R_0805_2012Metric
R26: 47k; R_0805_2012Metric
SW1: RotaryEncoder_Switch_MP; RotaryEncoder_Alps_EC11E-Switch_Vertical_H20mm
U1: USBLC6-2SC6; SOT-23-6
U2: BQ24075RGT; VQFN-16-1EP_3x3mm_P0.5mm_EP1.6x1.6mm
U3: DW01A; SOT-23-6
U4, U8, U9: TTP223 Touch Module
U5: TLV62569DBV; SOT-23-5
U6: MCP1640Cx-xCHY; SOT-23-6
U7: ESP32-C3-WROOM-02
U10: OLED I2C 0.91"; OLED I2C 0.91
U11: SN74LV1T34DBV; SOT-23-5

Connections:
+3V3: BZ1.1 (+), C11.1, C12.1, C16.2, C17.2, D3.1 (K), J3.1, J4.1, L1.2, R14.1, R18.2, R19.1, R20.1, R21.1, R22.1, R23.2, R28.1, U7.1 (3V3), U8.3 (VCC), U9.3 (VCC), U10.3 (VCC)
+5V: C14.1, C15.1, C20.1, C21.2, C22.2, C23.2, C24.2, C25.2, C26.2, C27.2, C28.2, C29.2, C30.2, C31.2, C32.2, C33.2, C34.2, C35.2, C36.2, D4.1 (VDD), D5.1 (VDD), D6.1 (VDD), D7.1 (VDD), D8.1 (VDD), D9.1 (VDD), D10.1 (VDD), D11.1 (VDD), D12.1 (VDD), D13.1 (VDD), D14.1 (VDD), D15.1 (VDD), D16.1 (VDD), D17.1 (VDD), D18.1 (VDD), D19.1 (VDD), R16.1, U6.5 (V_{OUT}), U11.5 (VCC)
BAT+: C7.1, J2.2, R9.1, U2.2 (BAT), U2.3 (BAT)
BAT-: C8.2, J2.1, Q1.1 (S1), U3.6 (GND)
CHG: D2.1 (K), D20.1 (K), U2.9 (~CHG)
D+: U1.4 (I/O2), U7.14 (IO19)
D-: U1.6 (I/O1), U7.13 (IO18)
DIN+: J1.A6 (D+), J1.B6 (D+), U1.3 (I/O2)
DIN-: J1.A7 (D-), J1.B7 (D-), U1.1 (I/O1)
GND: C1.1, C2.2, C3.2, C4.1, C5.1, C6.1, C7.2, C9.2, C10.2, C11.2, C12.2, C13.2, C14.2, C15.2, C16.1, C17.1, C18.1, C19.2, C20.2, C21.1, C22.1, C23.1, C24.1, C25.1, C26.1, C27.1, C28.1, C29.1, C30.1, C31.1, C32.1, C33.1, C34.1, C35.1, C36.1, D4.3 (VSS), D5.3 (VSS), D6.3 (VSS), D7.3 (VSS), D8.3 (VSS), D9.3 (VSS), D10.3 (VSS), D11.3 (VSS), D12.3 (VSS), D13.3 (VSS), D14.3 (VSS), D15.3 (VSS), D16.3 (VSS), D17.3 (VSS), D18.3 (VSS), D19.3 (VSS), J1.A1 (GND), J1.A12 (GND), J1.B1 (GND), J1.B12 (GND), J1.S1 (SHIELD), J3.4, J4.4, Q1.3 (S2), Q3.2 (S), Q4.2 (E), R1.2, R2.2, R3.1, R4.1, R5.1, R6.2, R10.2, R13.2, R15.2, R17.2, R26.2, SW1.C, SW1.MP, SW1.S2, U1.2 (GND), U2.4 (~CE), U2.6 (EN1), U2.8 (VSS), U2.15 (SYSOFF), U2.17 (VSS), U4.1 (GND), U5.2 (GND), U6.2 (GND), U7.9 (GND), U7.19 (GND), U8.1 (GND), U9.1 (GND), U10.4 (GND), U11.3 (GND)
IO1: C19.1, R25.2, R26.1, U7.17 (IO1)
IO2: R19.2, SW1.A, U7.16 (IO2)
IO3: R27.1, U7.15 (IO3)
IO4: U7.3 (IO4), U8.2 (I/O)
IO5: U7.4 (IO5), U9.2 (I/O)
IO8: R20.2, SW1.B, U7.7 (IO8)
IO9: R21.2, SW1.S1, U7.8 (IO9)
IO10: U7.10 (IO10), U11.2 (A)
unnamed: BZ1.2 (-), D3.2 (A), Q4.3 (C)
unnamed: D1.2 (A), R7.1
unnamed: D2.2 (A), R8.1
unnamed: D4.2 (DOUT), D5.4 (DIN)
unnamed: D5.2 (DOUT), D6.4 (DIN)
unnamed: D6.2 (DOUT), D7.4 (DIN)
unnamed: D7.2 (DOUT), D8.4 (DIN)
unnamed: D8.2 (DOUT), D9.4 (DIN)
unnamed: D9.2 (DOUT), D10.4 (DIN)
unnamed: D10.2 (DOUT), D11.4 (DIN)
unnamed: D11.2 (DOUT), D12.4 (DIN)
unnamed: D12.2 (DOUT), D13.4 (DIN)
unnamed: D13.2 (DOUT), D14.4 (DIN)
unnamed: D14.2 (DOUT), D15.4 (DIN)
unnamed: D15.2 (DOUT), D16.4 (DIN)
unnamed: D16.2 (DOUT), D17.4 (DIN)
unnamed: D17.2 (DOUT), D18.4 (DIN)
unnamed: D18.2 (DOUT), D19.4 (DIN)
unnamed: D20.2 (A), R28.2, U7.18 (IO0)
unnamed: J1.A5 (CC1), R1.1
unnamed: J1.B5 (CC2), R2.1
unnamed: Q1.6 (G1), U3.1 (OD)
unnamed: Q1.4 (G2), U3.3 (OC)
unnamed: Q2.1 (G), Q3.3 (D), R11.2
unnamed: Q3.1 (G), R12.2
unnamed: Q4.1 (B), R27.2
unnamed: R4.2, U2.12 (ILIM)
unnamed: R5.2, U2.16 (ISET)
unnamed: R3.2, U2.14 (TMR)
unnamed: R6.1, U2.1 (TS)
unnamed: R10.1, U3.2 (CS)
unnamed: C8.1, R9.2, U3.5 (VCC)
unnamed: R12.1, R13.1, U4.2 (I/O)
unnamed: R14.2, R15.1, U5.5 (FB)
unnamed: L1.1, U5.3 (SW)
unnamed: L2.2, U6.1 (SW)
unnamed: R16.2, R17.1, U6.4 (V_{FB})
unnamed: C18.2, R18.1, U7.2 (EN)
unnamed: R24.1, U11.4 (Y)
OUT: C9.1, C10.1, C13.1, L2.1, Q2.3 (D), R25.1, U5.1 (EN), U5.4 (VIN), U6.3 (EN), U6.6 (V_{IN})
PGOOD: D1.1 (K), U2.7 (~PGOOD)
RX: J3.2, U7.11 (IO20/RXD)
SCK: J4.3, R22.2, U7.6 (IO7), U10.2 (SCK)
SDA: J4.2, R23.1, U7.5 (IO6), U10.1 (SDA)
TX: J3.3, U7.12 (IO21/TXD)
VBUS: C1.2, C2.1, C3.1, C4.2, C5.2, J1.A4 (VBUS), J1.A9 (VBUS), J1.B4 (VBUS), J1.B9 (VBUS), U1.5 (VBUS), U2.13 (IN)
VCC: C6.2, Q2.2 (S), R7.2, R8.2, R11.1, U2.5 (EN2), U2.10 (OUT), U2.11 (OUT), U4.3 (VCC)
WS2812b: D4.4 (DIN), R24.2

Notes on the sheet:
ESP32-C3-Wroom-02
User Input
SEE DATASHEET FOR MORE INFORMATION: R_ILIM = K_ILIM / I_IN,max K_ILIM: 200mA - 500mA: 1525AOhm 500mA - 1,5A: 1610AOhm R_ISET = K_ISET / I_CHG K_ISET = 890AOhm R_TMR = t_MAXCHG / (10 * K_TMR) K_TMR = 48 s/kOhm
Boost Converter
Battery Protection
Logic Level Shifter
On/Off Touch Button
LED Ring
OLED Display
Buck Converter
Voltage Divider
LiPo Charger
Power Flags
Buzzer
USB-C Input

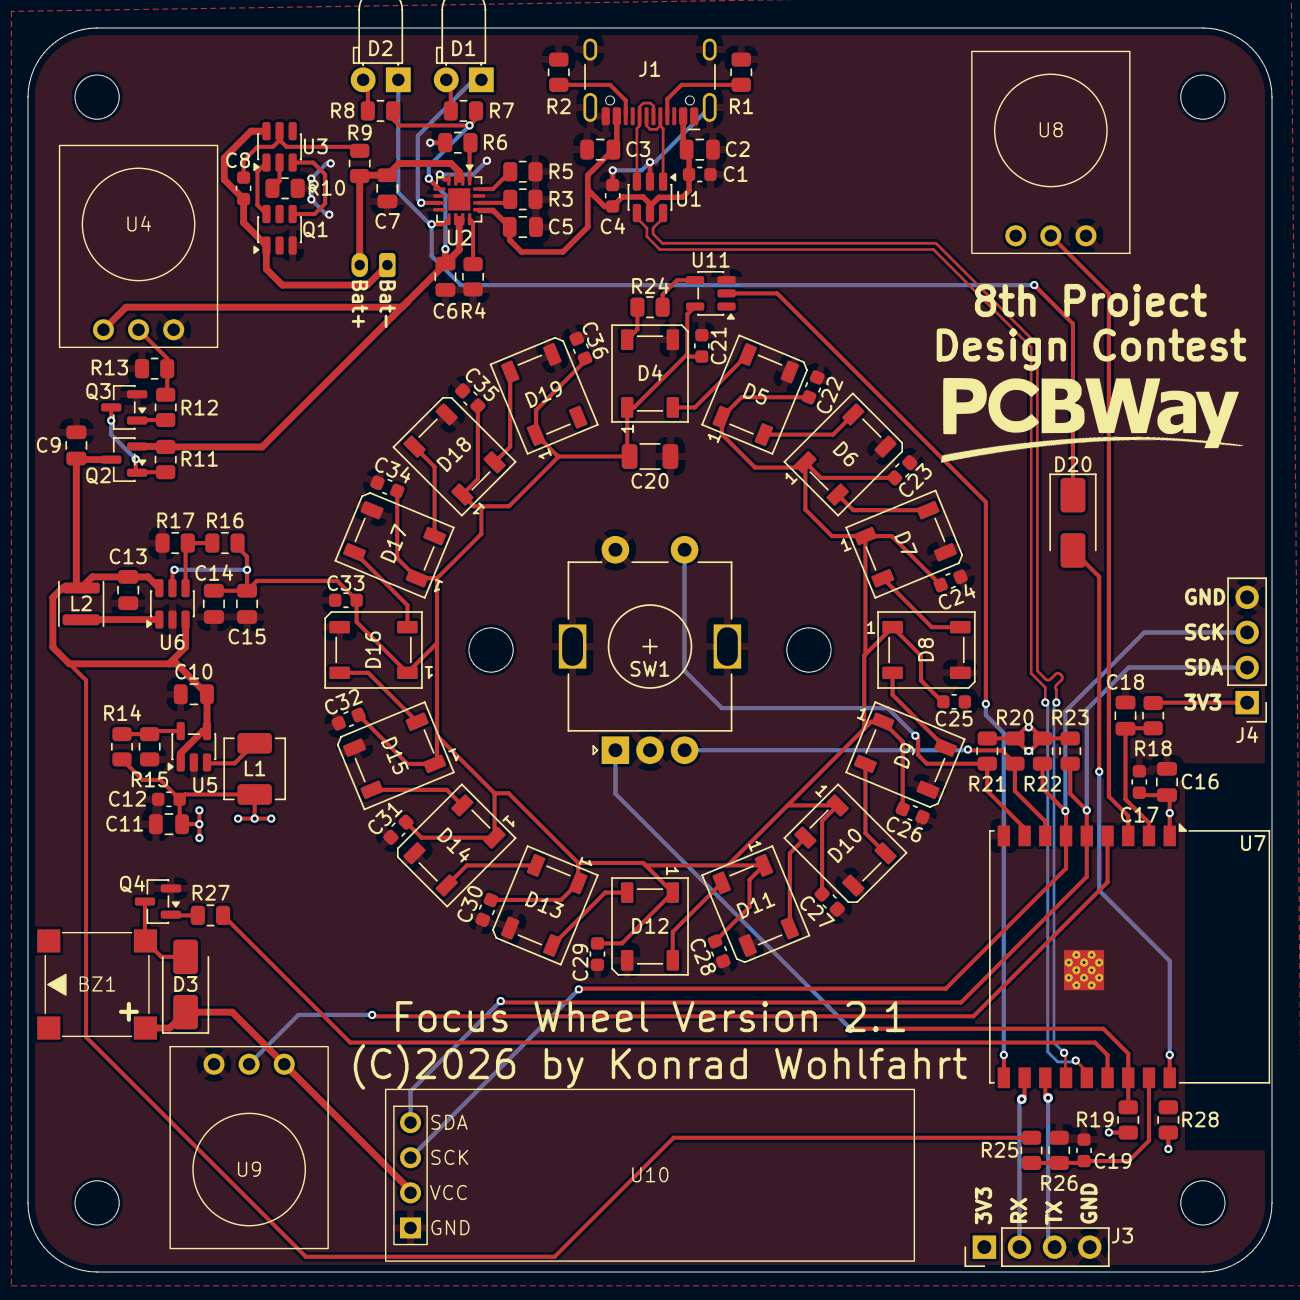
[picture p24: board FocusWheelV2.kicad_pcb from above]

Board: 2 copper layers, 90.0 x 90.0 mm, 107 parts (1 on the bottom side), 66 nets.

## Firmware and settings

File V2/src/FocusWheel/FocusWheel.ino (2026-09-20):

#include "preferences.h"
#include "displayFunctions.h"


// https://github.com/KonradWohlfahrt/Arduino-Timer-Library
#include <DonutStudioTimer.h>
Timer workTimer = Timer();
Timer breakTimer = Timer();
Timer twentyMinutes = Timer(0, 20);
Timer eyeTimer = Timer(0, 0, 30);


struct FocusWheelTimers {
  int8_t focusHours;
  int8_t focusMinutes;
  int8_t focusSeconds;
  int8_t breakHours;
  int8_t breakMinutes;
  int8_t breakSeconds;
  bool activateEyeTimer;
};
FocusWheelTimers currentTimers[4];
uint8_t lastSecond = 60;


struct FocusWheelSettings {
  uint8_t ledBrightnessIndex;
  uint8_t displayContrast;
  bool soundEnabledDefault;
  uint8_t melodyIndex;
};
FocusWheelSettings currentSettings;
#define BRIGHTNESS_OPTIONS 5
uint8_t _brightnessOptions[] = { 10, 15, 20, 25, 30 };
bool isSoundEnabled = false;
bool isSelected = false;
uint8_t currentSettingsIndex = 0;


enum FocusWheelMode {
  SelectTimerMode,
  WorkPhaseMode,
  AwaitInputMode,
  AwaitEyeTimerMode,
  EyeTimerMode,
  BreakPhaseMode,
  SettingsMode
};
FocusWheelMode currentMode = SelectTimerMode;
uint8_t currentModeIndex = 0;


uint8_t hue = 0;
uint8_t ledIndex = 0;


IRAM_ATTR void checkPosition() { encoder.tick(); }
void setup() 
{
  // --- INITIALIZE DISPLAY ---
  u8x8.begin();
  u8x8.setFont(u8x8_font_pressstart2p_f);
  u8x8.draw2x2String(0, 0, "FOCUS");
  u8x8.draw2x2String(5, 2, "WHEEL");


  // --- INITIALIZE PINS ---
  pinMode(TOP_BTN_PIN, INPUT);
  pinMode(BOTTOM_BTN_PIN, INPUT);
  pinMode(ROTARY_ENCODER_BTN_PIN, INPUT);
  pinMode(CHARGE_PIN, INPUT);
  pinMode(BATTERY_READ_PIN, INPUT);
  pinMode(BUZZER_PIN, OUTPUT);
  delay(250);


  // --- INITIALIZE EEPROM ---
  EEPROM.begin(1 + sizeof(FocusWheelSettings) + sizeof(FocusWheelTimers) * 4);
  delay(500);
  if (EEPROM.read(0) == 255) // if not used yet, EEPROM values will be 255
  {
    FocusWheelSettings defaultSettings(1, 50, true, 0);
    currentSettings = defaultSettings;

    FocusWheelTimers firstTimer(0, 30, 0, 0, 5, 0, false);
    FocusWheelTimers secondTimer(0, 45, 0, 0, 7, 0, true);
    FocusWheelTimers thirdTimer(1, 0, 0, 0, 15, 0, true);
    FocusWheelTimers fourthTimer(1, 30, 0, 0, 30, 0, true);
    currentTimers[0] = firstTimer;
    currentTimers[1] = secondTimer;
    currentTimers[2] = thirdTimer;
    currentTimers[3] = fourthTimer;

    EEPROM.write(0, 0);
    saveEEPROM();
  }
  else
    loadEEPROM();
  isSoundEnabled = currentSettings.soundEnabledDefault;
  u8x8.setContrast(currentSettings.displayContrast);
  u8x8.clearLine(0);
  

  // --- CHECK BATTERY ---
  checkBattery(true);
  

  // --- INITIALIZE LED RING ---
  FastLED.addLeds<WS2812B, LED_PIN, GRB>(leds, LED_COUNT).setCorrection(TypicalLEDStrip);
  FastLED.setMaxPowerInVoltsAndMilliamps(5, 250);
  FastLED.setBrightness(_brightnessOptions[currentSettings.ledBrightnessIndex]);


  // --- INITIALIZE TIMER SELECT MENU ---
  encoder.setPosition(0);
  drawTimerMenu(true);


  // --- ATTATCH INTERRUPTS FOR ROTARY ENCODER ---
  attachInterrupt(digitalPinToInterrupt(ROTARY_ENCODER_A_PIN), checkPosition, CHANGE);
  attachInterrupt(digitalPinToInterrupt(ROTARY_ENCODER_B_PIN), checkPosition, CHANGE);
}
void loop()
{
  updateLEDRing();

  checkButtons();
  checkBattery(false);
  refreshTimers();
  
  if (currentMode == WorkPhaseMode)
  {
    if (currentTimers[currentModeIndex].activateEyeTimer && twentyMinutes.isOver())
    {
      // only start eye timer if ~5 minutes of the work timer remain
      if ((workTimer.getTotalRemainingMilliseconds() / 1000) >= 300)
        awaitEyeTimer();
    }
    if (workTimer.isOver())
      endCurrentTimer(false);
  }
  if (currentMode == BreakPhaseMode)
  {
    if (breakTimer.isOver())
      endCurrentTimer(false);
  }
  if (currentMode == EyeTimerMode)
  {
    if (eyeTimer.isOver())
      endCurrentTimer(false);
  }
}


void loadEEPROM() 
{
  uint8_t currentAddress = 1;
  EEPROM.get(currentAddress, currentSettings);
  currentAddress += sizeof(FocusWheelSettings);
  for (uint8_t i = 0; i < 4; i++)
  {
    EEPROM.get(currentAddress, currentTimers[i]);
    currentAddress += sizeof(FocusWheelTimers);
  }
}
void saveEEPROM()
{
  uint8_t currentAddress = 1;
  EEPROM.put(currentAddress, currentSettings);
  currentAddress += sizeof(FocusWheelSettings);
  for (uint8_t i = 0; i < 4; i++)
  {
    EEPROM.put(currentAddress, currentTimers[i]);
    currentAddress += sizeof(FocusWheelTimers);
  }
  delay(250);
  EEPROM.commit();
  delay(250);
}


void checkButtons()
{
  // enable/disable sound
  if (bottomBtn()) 
  {
    while (bottomBtn())
    {
      delay(1); // avoid stack overflow
      updateLEDRing();
      checkBattery(false);
    }

    isSoundEnabled = !isSoundEnabled;
    displaySoundSetting(isSoundEnabled);

    if (isSoundEnabled)
      beep();
  }

  // rotary encoder button
  if (middleBtn()) 
  {
    if (isSoundEnabled)
      beep();

    while (middleBtn())
    {
      delay(1); // avoid stack overflow
      updateLEDRing();
      checkBattery(false);
    }

    if (currentMode == SelectTimerMode)
    {
      currentModeIndex = encoder.getPosition() % 4;
      workTimer.setTimer(currentTimers[currentModeIndex].focusHours, currentTimers[currentModeIndex].focusMinutes, currentTimers[currentModeIndex].focusSeconds);
      breakTimer.setTimer(currentTimers[currentModeIndex].breakHours, currentTimers[currentModeIndex].breakMinutes, currentTimers[currentModeIndex].breakSeconds);

      currentMode = WorkPhaseMode;
      startCurrentTimer();
    }
    else if (currentMode == WorkPhaseMode) 
    {
      if (currentTimers[currentModeIndex].activateEyeTimer)
        twentyMinutes.setPause(!workTimer.isPaused());
      workTimer.setPause(!workTimer.isPaused());
    }
    else if (currentMode == AwaitInputMode)
    {
      currentMode = BreakPhaseMode;
      startCurrentTimer();
    }
    else if (currentMode == AwaitEyeTimerMode)
    {
      currentMode = EyeTimerMode;
      startCurrentTimer();
    }
    else if (currentMode == BreakPhaseMode)
      breakTimer.setPause(!breakTimer.isPaused());
    else if (currentMode == SettingsMode)
    {
      uint8_t pos = encoder.getPosition() % 8;
      if (!isSelected && pos >= 4)
      {
        currentSettingsIndex = pos;
        editTimer(pos - 4);

        encoder.setPosition(currentSettingsIndex);
        drawSettingsMenu(true);
        return;
      }

      isSelected = !isSelected;
      if (isSelected)
      {
        currentSettingsIndex = pos;
        if (currentSettingsIndex == 3)
          playMelody(melodys[currentSettings.melodyIndex], durations[currentSettings.melodyIndex]);
      } 
      else 
      {
        encoder.setPosition(currentSettingsIndex);
      }

      drawSettingsMenu(false);
    }
  }

  // skip or enter settings
  if (topBtn()) 
  {
    if (isSoundEnabled)
      beep();

    while (topBtn())
    {
      delay(1); // avoid stack overflow
      updateLEDRing();
      checkBattery(false);
    }

    if (currentMode == SelectTimerMode)
    {
      currentModeIndex = encoder.getPosition() % 4;
      currentMode = SettingsMode;
      currentSettingsIndex = 0;
      encoder.setPosition(0);
      isSelected = false;

      drawSettingsMenu(true);
    }
    else if (currentMode == WorkPhaseMode)
      endCurrentTimer(true);
    else if (currentMode == AwaitInputMode)
    {
      currentMode = BreakPhaseMode;
      startCurrentTimer();
    }
    else if (currentMode == AwaitEyeTimerMode)
    {
      currentMode = EyeTimerMode;
      endCurrentTimer(true);
    }
    else if (currentMode == EyeTimerMode)
      endCurrentTimer(true);
    else if (currentMode == BreakPhaseMode)
      endCurrentTimer(true);
    else if (currentMode == SettingsMode && !isSelected) 
    {
      saveEEPROM();

      encoder.setPosition(currentModeIndex);
      currentMode = SelectTimerMode;
      u8x8.clearLine(0);
      checkBattery(true);
      drawTimerMenu(true);
    }
  }

  // wheel rotated
  RotaryEncoder::Direction dir = encoder.getDirection();
  if (dir != RotaryEncoder::Direction::NOROTATION)
  {
    if (currentMode == WorkPhaseMode || currentMode == AwaitInputMode || currentMode == BreakPhaseMode)
      return;

    if(isSoundEnabled)
      beep(400, 20);

    if (encoder.getPosition() < 0)
    {
      if (currentMode == SelectTimerMode)
        encoder.setPosition(3);
      else if (currentMode == SettingsMode)
        encoder.setPosition(7);
    }

    if (currentMode == SelectTimerMode) {
      updateLEDRing();
      drawTimerMenu(false);
    }
    else if (currentMode == SettingsMode) 
    {
      if (isSelected)
      {
        if (dir == RotaryEncoder::Direction::CLOCKWISE)
        {
          switch(currentSettingsIndex)
          {
            case 0:
              currentSettings.ledBrightnessIndex = (currentSettings.ledBrightnessIndex + 1) % BRIGHTNESS_OPTIONS;
              FastLED.setBrightness(_brightnessOptions[currentSettings.ledBrightnessIndex]);
              break;
            case 1:
              if (currentSettings.displayContrast < 250)
                currentSettings.displayContrast += 50;
              else
                currentSettings.displayContrast = 0;
              u8x8.setContrast(currentSettings.displayContrast);
              break;
            case 2:
              currentSettings.soundEnabledDefault = !currentSettings.soundEnabledDefault;
              break;
            case 3:
              currentSettings.melodyIndex = (currentSettings.melodyIndex + 1) % MELODYS;
              playMelody(melodys[currentSettings.melodyIndex], durations[currentSettings.melodyIndex]);
              break;
          }
        }
        else if (dir == RotaryEncoder::Direction::COUNTERCLOCKWISE)
        {
          switch(currentSettingsIndex)
          {
            case 0:
              currentSettings.ledBrightnessIndex = (currentSettings.ledBrightnessIndex - 1) < 0 ? (BRIGHTNESS_OPTIONS - 1) : (currentSettings.ledBrightnessIndex - 1);
              FastLED.setBrightness(_brightnessOptions[currentSettings.ledBrightnessIndex]);
              break;
            case 1:
              if (currentSettings.displayContrast > 0)
                currentSettings.displayContrast -= 50;
              else
                currentSettings.displayContrast = 250;
              u8x8.setContrast(currentSettings.displayContrast);
              break;
            case 2:
              currentSettings.soundEnabledDefault = !currentSettings.soundEnabledDefault;
              break;
            case 3:
              currentSettings.melodyIndex = (currentSettings.melodyIndex - 1) < 0 ? (MELODYS - 1) : (currentSettings.melodyIndex - 1);
              playMelody(melodys[currentSettings.melodyIndex], durations[currentSettings.melodyIndex]);
              break;
          }
        }
      }
      updateLEDRing();
      drawSettingsMenu(false);
    }
  }
}
void checkBattery(bool force) 
{
  bool check = false;
  EVERY_N_SECONDS(5) { check = true; }

  if (check || force)
  {
    if (isBatteryPowered() && getBatteryLevel() <= 0)
    {
      beep(250);

      fill_solid(leds, LED_COUNT, 0);
      FastLED.show();

      u8x8.clear();
      u8x8.drawString(0, 0, "Low Battery");
      u8x8.drawTile(13, 0, 3, (uint8_t*)_batteryBackgroundCharging);
      u8x8.drawTile(14, 0, 1, (uint8_t*)_batteryLow);

      beep();

      esp_deep_sleep_start();
    }

    displaySoundSetting(isSoundEnabled);
    displayBatteryStatus(currentMode != SettingsMode);
  }
}



void updateLEDRing()
{
  if (currentMode == SelectTimerMode)
  {
    EVERY_N_MILLISECONDS(15)
    { 
      hue++;
      fill_rainbow(leds, LED_COUNT, hue, 255 / LED_COUNT);

      uint8_t start = (4 * (encoder.getPosition() % 4) + 5) % LED_COUNT;
      uint8_t end = start + 11;

      for (uint8_t i = start; i < end; i++)
        leds[i % LED_COUNT] = 0;

      FastLED.show();
    }
  }
  else if (currentMode == WorkPhaseMode)
  {
    EVERY_N_MILLISECONDS(20) { drawCountdownRing(workTimer, CRGB::Red, CRGB::Yellow); }
  }
  else if (currentMode == AwaitInputMode || currentMode == AwaitEyeTimerMode)
  {
    EVERY_N_MILLISECONDS(20) 
    {
      ledIndex = (ledIndex + 1) % LED_COUNT;
      leds[ledIndex] = CRGB::GhostWhite;
      fadeToBlackBy(leds, LED_COUNT, 64); // 64/255 = 25%
      FastLED.show(); 
    }
  }
  else if (currentMode == EyeTimerMode)
  {
    EVERY_N_MILLISECONDS(20)  { drawCountdownRing(eyeTimer, CRGB::Blue, CRGB::Yellow); }
  }
  else if (currentMode == BreakPhaseMode)
  {
    EVERY_N_MILLISECONDS(20) { drawCountdownRing(breakTimer, CRGB::Green, CRGB::Yellow); }
  }
  else if (currentMode == SettingsMode)
  {
    EVERY_N_MILLISECONDS(15)
    { 
      hue++;
      fill_solid(leds, LED_COUNT, isSelected ? CRGB::Gold : CRGB::Orange);

      uint8_t index = isSelected ? currentSettingsIndex : encoder.getPosition() % 8;
      uint8_t start = (2 * index + 2) % LED_COUNT;
      uint8_t end = start + 14;

      for (uint8_t i = start; i < end; i++)
        leds[i % LED_COUNT] = 0;

      FastLED.show();
    }
  }
}
void refreshTimers()
{
  if (currentMode == WorkPhaseMode)
  {
    if (lastSecond != workTimer.getRemainingSeconds())
    {
      display2x2Countdown(workTimer, true, 1);
      lastSecond = workTimer.getRemainingSeconds();
    }
  }
  else if (currentMode == BreakPhaseMode)
  {
    if (lastSecond != breakTimer.getRemainingSeconds())
    {
      display2x2Countdown(breakTimer, true, 1);
      lastSecond = breakTimer.getRemainingSeconds();
    }
  }
  else if (currentMode == EyeTimerMode)
  {
    if (lastSecond != eyeTimer.getRemainingSeconds())
    {
      draw2x2Countdown(eyeTimer.getRemainingSeconds(), 1);
      lastSecond = eyeTimer.getRemainingSeconds();
    }
  }
}


void drawTimerMenu(bool fullReset)
{
  uint8_t index = encoder.getPosition() % 4;
  if (fullReset)
  {
    u8x8.clearLine(1);
    u8x8.clearLine(2);
    u8x8.drawString(0, 1, "Work:");
    u8x8.drawString(0, 2, "Break:");
  }
  drawCountdown(currentTimers[index].focusHours, currentTimers[index].focusMinutes, currentTimers[index].focusSeconds, 7, 1);
  drawCountdown(currentTimers[index].breakHours, currentTimers[index].breakMinutes, currentTimers[index].breakSeconds, 7, 2);
  drawSlider(3, 4, index);
}
void drawSettingsMenu(bool fullReset)
{
  uint8_t index = isSelected ? currentSettingsIndex : encoder.getPosition() % 8;

  if (fullReset)
  {
    checkBattery(true);
    u8x8.drawString(2, 0, "Settings");
  }

  u8x8.clearLine(1);
  u8x8.clearLine(2);
  if (index == 0)
  {
    u8x8.drawString(0, 1, "Brightness");
    if (isSelected)
      u8x8.setInverseFont(true);
    u8x8.draw2x2String(11, 1, String(_brightnessOptions[currentSettings.ledBrightnessIndex]).c_str());
    if (isSelected)
      u8x8.setInverseFont(false);
  }
  else if (index == 1) 
  {
    u8x8.drawString(0, 1, "Contrast");
    if (isSelected)
      u8x8.setInverseFont(true);
    if (currentSettings.displayContrast >= 100)
      u8x8.draw2x2String(9, 1, String(currentSettings.displayContrast).c_str());
    else if (currentSettings.displayContrast >= 10)
      u8x8.draw2x2String(11, 1, String(currentSettings.displayContrast).c_str());
    else
      u8x8.draw2x2String(13, 1, String(currentSettings.displayContrast).c_str());
    if (isSelected)
      u8x8.setInverseFont(false);
  }
  else if (index == 2) 
  {
    u8x8.drawString(0, 1, "Default");
    u8x8.drawString(0, 2, "Sound");
    if (isSelected)
      u8x8.setInverseFont(true);
    if (currentSettings.soundEnabledDefault)
      u8x8.draw2x2String(11, 1, "ON");
    else
      u8x8.draw2x2String(9, 1, "OFF");
    if (isSelected)
      u8x8.setInverseFont(false);
  }
  else if (index == 3) 
  {
    u8x8.drawString(0, 1, "Melody");
    if (isSelected)
      u8x8.setInverseFont(true);
    u8x8.draw2x2String(14, 1, String(currentSettings.melodyIndex + 1).c_str());
    if (isSelected)
      u8x8.setInverseFont(false);
  }
  else
  {
    u8x8.draw2x2String(0, 1, ("Timer " + String(index - 3)).c_str());
  }

  drawSlider(3, 8, index);
}


void display2x2Countdown(Timer &t, bool started, uint8_t y) 
{
  uint8_t s = started ? t.getRemainingSeconds() : t.getSeconds();
  uint8_t m = started ? t.getRemainingMinutes() : t.getMinutes();
  uint8_t h = started ? t.getRemainingHours() : t.getHours();

  draw2x2Countdown(h, m, s, y);
}
void drawCountdownRing(Timer &t, CRGB color, CRGB pauseColor)
{
  if (!t.isPaused()) 
  {
    float p = constrain((float)t.getTotalRemainingMilliseconds() / (float)t.getTotalMilliseconds(), 0.0f, 100.0f);
    uint8_t count = (uint8_t)(p * LED_COUNT);
    for (uint8_t i = 0; i < LED_COUNT; i++)
    {
      if (i < count)
        leds[i] = color;
      else if (i == count) 
      {
        leds[i] = color;
        float n = p * LED_COUNT - count;
        leds[i].fadeToBlackBy(255 - (uint8_t)(n * 255));
      }
      else
        leds[i] = CRGB::Black;
    }
    FastLED.show();
  }
  else 
  {
    fadeToBlackBy(leds, LED_COUNT, 16); // 16/255 ~ 6%
    EVERY_N_MILLISECONDS(500) { leds[random8(LED_COUNT)] = pauseColor; }
    FastLED.show();
  }
}


void startCurrentTimer()
{
  lastSecond = 60;
  if (currentMode == WorkPhaseMode)
  {
    workTimer.begin();
    if (currentTimers[currentModeIndex].activateEyeTimer)
      twentyMinutes.begin();
      
    u8x8.clear();
    checkBattery(true);
    drawCountdownText(3, "Work Phase!");
  }
  else if (currentMode == AwaitInputMode)
  {
    checkBattery(true);
    display2x2Countdown(breakTimer, false, 1);
    drawCountdownText(2, "Break Phase!");
  }
  else if (currentMode == EyeTimerMode)
  {
    eyeTimer.begin();
    checkBattery(true);
    draw2x2Countdown(eyeTimer.getSeconds(), 1);
    drawCountdownText(3, "20-20-Rule");
  }
  else if (currentMode == BreakPhaseMode)
  {
    breakTimer.begin();
  }
}
void endCurrentTimer(bool skipFiller)
{
  if (currentMode == WorkPhaseMode)
  {
    if (!skipFiller)
    {
      timerEndAnimation(CRGB::Red);
      currentMode = AwaitInputMode;
    }
    else 
    {
      currentMode = BreakPhaseMode;
      checkBattery(true);
      drawCountdownText(2, "Break Phase!");
    }

    startCurrentTimer();
  }
  else if (currentMode == BreakPhaseMode)
  {
    if (!skipFiller)
      timerEndAnimation(CRGB::Green);
    currentMode = SelectTimerMode;

    u8x8.clear();
    encoder.setPosition(currentModeIndex);
    drawTimerMenu(true);
    checkBattery(true);
  }
  else if (currentMode == EyeTimerMode)
  {
    if (!skipFiller && isSoundEnabled)
      doubleBeep();

    currentMode = WorkPhaseMode;
    workTimer.setPause(false);
    twentyMinutes.begin();

    lastSecond = 60;
    drawCountdownText(3, "Work Phase!");
    checkBattery(true);
  }
}
void awaitEyeTimer()
{
  if (isSoundEnabled)
    doubleBeep();

  lastSecond = 60;
  workTimer.setPause(true);
  currentMode = AwaitEyeTimerMode;
  u8x8.clear();
  checkBattery(true);
  draw2x2Countdown(eyeTimer.getSeconds(), 1);
  drawCountdownText(3, "20-20-Rule");
}
void timerEndAnimation(CRGB color)
{
  u8x8.clear();
  u8x8.draw2x2String(4, 2, "END!");

  uint8_t n = 0;
  uint8_t half = (LED_COUNT / 2);

  uint32_t time = millis();
  uint32_t next = 0;
  uint8_t i = 0;

  while (true)
  {
    EVERY_N_MILLISECONDS(25)
    {
      n = (n + 1) % half;
      leds[n] = color;
      leds[n + half] = color;
      fadeToBlackBy(leds, LED_COUNT, 96); // 96/255 = ~38%
      FastLED.show(); 
    }

    if (millis() - time >= next)
    {
      uint16_t dur = noteDuration(durations[currentSettings.melodyIndex][i]);
      if (isSoundEnabled)
        beep(melodys[currentSettings.melodyIndex][i], dur);
      i++;
      next = dur * 1.3;
      time = millis();
    }

    if (i >= MELODY_LENGTH)
        break;
    
    delay(1);
  }
}
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

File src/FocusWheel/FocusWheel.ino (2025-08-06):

#include "preferences.h"

#include <DonutStudioTimer.h>
Timer workTimer = Timer();
Timer breakTimer = Timer();

IRAM_ATTR void checkPosition() { encoder.tick(); }


const CRGB _timerColors[5] = { CHSV(25, 255, 255), CHSV(76, 255, 255), CHSV(127, 255, 255), CHSV(178, 255, 255), CHSV(229, 255, 255) };


uint8_t _lineTiles[8] = { 0xf0, 0xf0, 0xf0, 0xf0, 0xf0, 0xf0, 0xf0, 0xf0 };
uint8_t _workTimes[5][3] = {
//  h,  m, s
  { 0, 30, 0 },
  { 0, 45, 0 },
  { 1, 0, 0 },
  { 1, 30, 0 },
  { 0, 0, 0 } // can be edited, saved to eeprom
};
uint8_t _breakTimes[5][3] = {
//  h, m, s
  { 0, 5, 0 },
  { 0, 7, 0 },
  { 0, 15, 0 },
  { 0, 30, 0 },
  { 0, 0, 0 } // can be edited, saved to eeprom
};

int8_t selectedTimer = 0;
bool timerStarted = false;
bool isInWorkPhase = true;

uint8_t ledIndex;


void setup() 
{
  // --- INITIALIZE PINS ---
  pinMode(BUZZER_PIN, OUTPUT);
  pinMode(SLIDER_PIN, INPUT);
  analogSetAttenuation(ADC_2_5db);
  pinMode(SIDE_BTN_PIN, INPUT);
  pinMode(ROTARY_ENC_BTN_PIN, INPUT);

  // --- ATTATCH INTERRUPTS FOR ROTARY ENCODER ---
  attachInterrupt(digitalPinToInterrupt(ROTARY_ENC_A_PIN), checkPosition, CHANGE);
  attachInterrupt(digitalPinToInterrupt(ROTARY_ENC_B_PIN), checkPosition, CHANGE);

  // --- INITIALIZE LED RING ---
  FastLED.addLeds<WS2812B, LED_PIN, GRB>(leds, LED_COUNT).setCorrection(TypicalLEDStrip);
  FastLED.setBrightness(30);
  
  // --- INITIALIZE DISPLAY ---
  u8x8.begin();
  u8x8.setFont(u8x8_font_pressstart2p_f);

  // --- INITIALIZE EEPROM AND LOAD SLIDER VALUES ---
  EEPROM.begin(10);
  delay(250);
  loadSliderValues();
  _workTimes[4][0] = constrain(EEPROM.read(4), 0, 10); // hours
  _workTimes[4][1] = constrain(EEPROM.read(5), 0, 59); // minutes
  _workTimes[4][2] = constrain(EEPROM.read(6), 0, 59); // seconds
  _breakTimes[4][0] = constrain(EEPROM.read(7), 0, 10); // hours
  _breakTimes[4][1] = constrain(EEPROM.read(8), 0, 59); // minutes
  _breakTimes[4][2] = constrain(EEPROM.read(9), 0, 59); // seconds

  workTimer.setTimer(_workTimes[0][0], _workTimes[0][1], _workTimes[0][2]);
  breakTimer.setTimer(_breakTimes[0][0], _breakTimes[0][1], _breakTimes[0][2]);
  drawSelectTimer(true);
}
void loop()
{
  if (middleBtn())
  {
    playSound();
    while(middleBtn()) 
    {
      refreshLEDs();
      delay(2);
    }

    // start timer
    if (!timerStarted)
    {
      timerStarted = true;
      isInWorkPhase = true;
      workTimer.setTimer(_workTimes[selectedTimer][0], _workTimes[selectedTimer][1], _workTimes[selectedTimer][2]);
      breakTimer.setTimer(_breakTimes[selectedTimer][0], _breakTimes[selectedTimer][1], _breakTimes[selectedTimer][2]);
      workTimer.begin();
      u8x8.clear();
      u8x8.drawString(3, 0, "Work Phase!");
    }
    // pause timer
    else
    {
      if (isInWorkPhase)
        workTimer.setPause(!workTimer.isPaused());
      else
        breakTimer.setPause(!breakTimer.isPaused());
    }
  }

  if (rightBtn())
  {
    playSound();
    while(rightBtn()) 
    {
      refreshLEDs();
      delay(2);
    }

    if (!timerStarted)
      editTimer();
    else
      endCurrentTimer(false);
  }
  
  if (!timerStarted) 
  {
    if (getDirection(selectedTimer)) 
    {
      if (selectedTimer < 0)
        selectedTimer = 4;
      else if (selectedTimer > 4)
        selectedTimer = 0;
      drawSelectTimer(false);
    }
  }
  else
  {
    if (isInWorkPhase)
    {
      if (workTimer.isOver()) 
        endCurrentTimer(true);
    }
    else
    {
      if (breakTimer.isOver())
        endCurrentTimer(true);
    }
  }

  refreshLEDs();
  refreshDisplay();
}

void drawCountdownRing(Timer& t, CRGB color)
{
  if (!t.isPaused()) 
  {
    EVERY_N_MILLISECONDS(25) 
    {
      float percent = (float)t.getTotalRemainingMilliseconds() / t.getTotalMilliseconds();
      int count = percent * LED_COUNT;
      for (int i = 0; i < LED_COUNT; i++)
      {
        if (i < count)
          leds[i] = color;
        else if (i == count) 
        {
          float n = percent * LED_COUNT - count;
          leds[i] = color;
          leds[i].fadeToBlackBy(255 - (uint8_t)(n * 255));
        }
        else
          leds[i] = CRGB::Black;
      }
      FastLED.show();
    }
  }
  else 
  {
    EVERY_N_MILLISECONDS(25) 
    {
      fadeToBlackBy(leds, LED_COUNT, 16); // 16/255 = 6%
      FastLED.show();
    }
    EVERY_N_MILLISECONDS(250) 
    {
      leds[random8(LED_COUNT)] = CRGB::Yellow;
      FastLED.show();
    }
  }
}
void drawCountdown(Timer& t, bool started, uint8_t y) 
{
  uint8_t s = started ? t.getRemainingSeconds() : t.getSeconds();
  uint8_t m = started ? t.getRemainingMinutes() : t.getMinutes();
  uint8_t h = started ? t.getRemainingHours() : t.getHours();

  drawCountdown(h, m, s, y);
}
void drawCountdown(uint8_t h, uint8_t m, uint8_t s, uint8_t y) 
{
  String text = "";
  if (h < 10)
    text += "0";
  text += String(h) + ":";
  if (m < 10)
    text += "0";
  text += String(m) + ":";
  if (s < 10)
    text += "0";
  text += String(s);

  u8x8.draw2x2String(0, y, text.c_str());
}
void drawUnderline(uint8_t selection, uint8_t y)
{
  u8x8.clearLine(y);

  uint8_t start = (2 - selection) * 6;
  uint8_t end = start + 4;
  for (int i = start; i < end; i++)
    u8x8.drawTile(i, y, 1, _lineTiles);
}
void drawSelectTimer(bool fullReset)
{
  if (fullReset) 
  {
    u8x8.drawString(2, 0, "Focus Wheel!");
    u8x8.drawString(0, 1, "Work:");
    u8x8.drawString(0, 2, "Break:");
  }
  
  // WORK TIME
  String s = "";
  if (_workTimes[selectedTimer][0] < 10)
    s += "0";
  s += String(_workTimes[selectedTimer][0]) + ":";
  if (_workTimes[selectedTimer][1] < 10)
    s += "0";
  s += String(_workTimes[selectedTimer][1]) + ":";
  if (_workTimes[selectedTimer][2] < 10)
    s += "0";
  s += String(_workTimes[selectedTimer][2]);
  u8x8.drawString(7, 1, s.c_str());

  // BREAK TIME
  s = "";
  if (_breakTimes[selectedTimer][0] < 10)
    s += "0";
  s += String(_breakTimes[selectedTimer][0]) + ":";
  if (_breakTimes[selectedTimer][1] < 10)
    s += "0";
  s += String(_breakTimes[selectedTimer][1]) + ":";
  if (_breakTimes[selectedTimer][2] < 10)
    s += "0";
  s += String(_breakTimes[selectedTimer][2]);
  u8x8.drawString(7, 2, s.c_str());

  // select indication
  u8x8.clearLine(3);
  uint8_t start = selectedTimer * 3;
  uint8_t end = start + 3;
  for (int i = start; i < end; i++)
    u8x8.drawTile(i, 3, 1, _lineTiles);
}
bool getDirection(int8_t& value)
{
  RotaryEncoder::Direction dir = encoder.getDirection();
  if (dir != RotaryEncoder::Direction::NOROTATION)
  {
    value += (dir == RotaryEncoder::Direction::CLOCKWISE) ? -1 : 1;
    return true;
  }
  return false;
}
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

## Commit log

2025-08-06 update knob stl
    [Knob.stl]
2026-01-26 Added Focus Wheel Version 2
    [BOM_FocusWheel_V2.csv, BOM_FocusWheel_V2_1.csv, Fading Knob.stl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]
2026-09-20 added diffuser
    [FocusWheel_Diffuser.stl, FocusWheel_Knob.stl]

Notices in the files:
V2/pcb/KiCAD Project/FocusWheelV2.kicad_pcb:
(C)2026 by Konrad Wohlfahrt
